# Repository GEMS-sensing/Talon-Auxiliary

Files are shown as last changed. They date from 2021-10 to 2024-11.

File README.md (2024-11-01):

<!-- [![DOI](https://zenodo.org/badge/678911830.svg)](https://zenodo.org/doi/10.5281/zenodo.13377368) -->

# Talon-Auxiliary
Talon daughterboard for [Flight data logger](https://github.com/GEMS-sensing/DFM_-_Flight?tab=readme-ov-file). Designed to interface with [Kestrel](https://github.com/GEMS-sensing/Project-Kestrel) main board. This board is designed to provide data logger with support to interface with analog and pulsed digital signals.
# Repo Roadmap
#### [Documents](Documents/) 

General document and image storage for repo and README

#### [Hardware](Hardware/)

Current board files (Eagle), Bill of Materials (BoM), and other design documents

#### [Production](Production/)

Contains the various Gerber and pick and place files required to have the Printed Circuit Boards (PCBs) manufactured or populated 

#### [Software](Software/)

The software associated with the piece of hardware, this is usually diagnostic software used for verifying or investigating the hardware

<!-- #### [Mechanical](Mechanical/)

Mechanical design files and assembly documents -->

<!-- #### [Testing](Testing/)

Scripts and results from the testing process and development process. Contains more detailed information about documented issues among other testing. 
 -->

## Overview
* **Type:** Talon
* **Interfaces:** Analog, digital, digital (open drain)
* **Release Version:** v1.5 - 2023/05/15

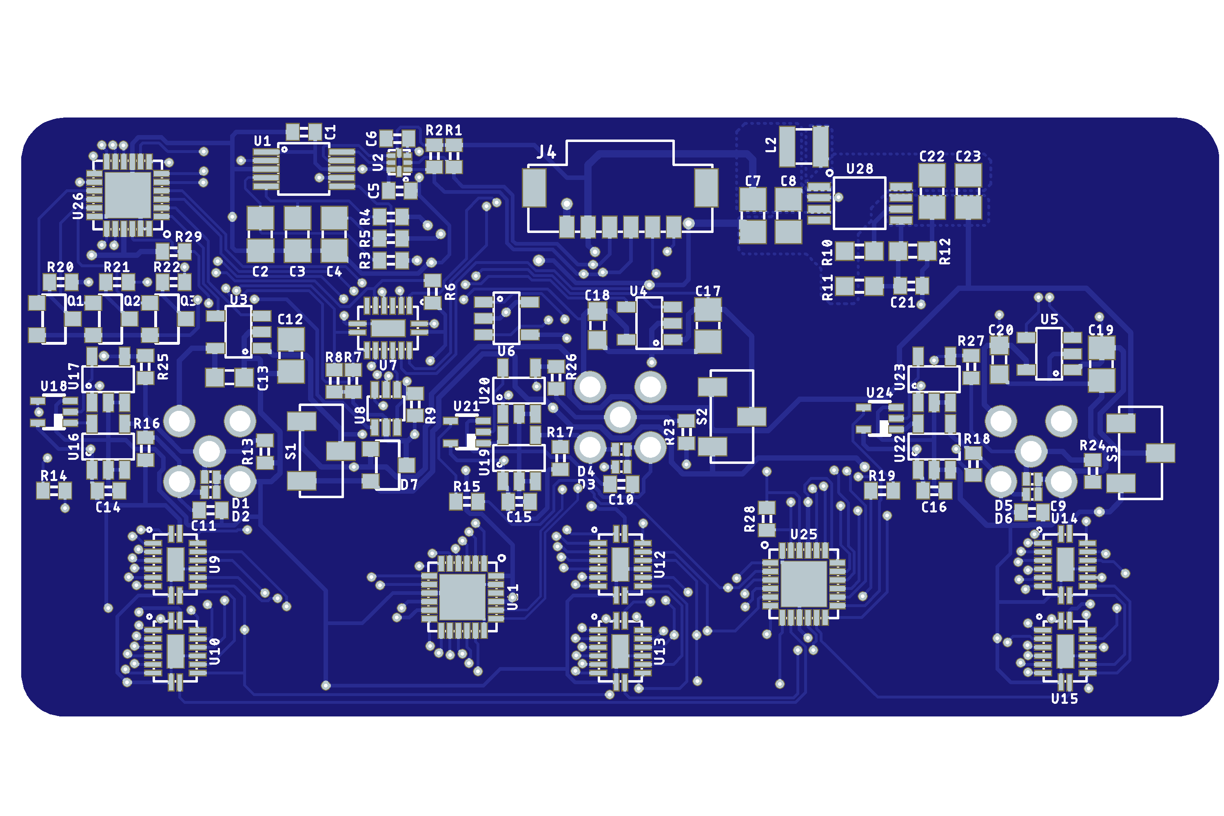
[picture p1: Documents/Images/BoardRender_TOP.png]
PCB render image, top


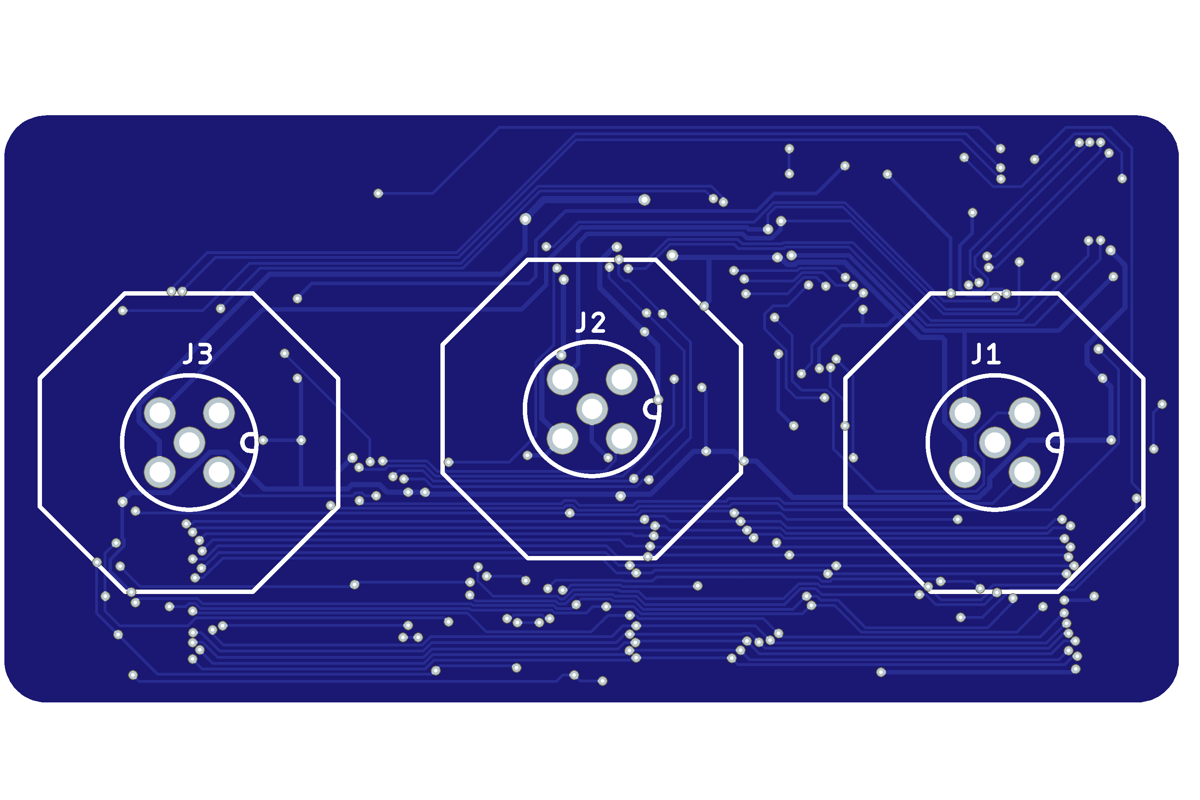
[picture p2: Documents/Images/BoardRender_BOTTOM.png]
PCB render image, bottom


<!-- ![Haar v0.0 - Bottom](Documents/Images/Haar_0v0_Bottom_Cropped.jpg) -->

## Features
### On-Board
* High precision ADC interface
	* 5V input
	* PGA
	* 16 bit (93.75 &mu;V @ 5V input, 3.9 &mu;V @ 0.25V input)
	* up to 860 SPS (reduced resolution)
* Hardware pulse counter
	* Reduces power consumption of logger by eliminating need to wake up SoM for frequent pulse interrupts 
	* 16 bit (65536) pulse count limit
	* Analog front end with hysteresis to deal with noisy inputs
	* Support for self diagnostics to allow for automated testing of operation 
* Push-pull and Open-drain compatible inputs 
* Load switch control for each port with current limiting 
* Manual switches to select each port between 3v3 and 5v power/logic
	* Chosen to be manual to prevent a firmware bug from damaging a sensor
* EEPROM with UUID built in - can store additional values defined by firmware to track offsets, etc
* ESD protected inputs

### Interface - Sensor
* I<sup>2</sup>C data interface
* M12 circular connector 

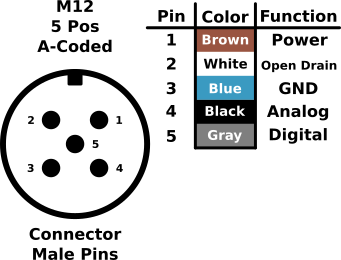
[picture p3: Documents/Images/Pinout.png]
Pinout


<!-- <picture>
  <source media="(prefers-color-scheme: dark)" srcset="Documents/Images/Pinout_LIGHT.png">
  <img alt="Hedorah Connector Pinout" src="Documents/Images/Pinout.png">
</picture> -->

| **Pin** | **Connection** | **Description** |
|---|---| --- |
| 1 | Power (3.3V  **OR** 5V) | Output power to sensors, limited to 50mA continuous current, voltage level is selected by DIP switch next to each port |
| 2 | Open Drain | Input for switch based sensors - 10k&Omega; pullup to Power rail|
| 3 | Ground | Power and data ground for system |
| 4 | Analog | Analog voltage input |
| 5 | Digital | Digital pulse input |

#### Sensor Wiring

- Switch based sensors
	- e.g. reed switch, hall effect, etc
	- Devices where the sensor open or closes a switch depending on state
	- Wire switch between Ground and Open Drain lines
	- WARNING: The Talon will apply rail power to the switch line via a pullup resistor - ensure the sensor is rated for the rail voltage being used (3.3V or 5V)
	- NOTE: To limit power consumption, only recommended for Nominally Open (NO) switches
- Pulse based sensors
	- e.g. microcontroller pulse outputs, basic digital sensors, etc
	- Devices where the output is either 0V or a logic voltage based based on a sensor state
	- Wire grounds together and wire the pulse output to the Digital pin, wire Power to sensor if needed
	- NOTE: The digital input is 5V tolerant regardless of the voltage on the power bus
- Analog based sensors
	- e.g. Potentiometers, basic sensors with variable voltage output, etc
	- Devices where the output is a voltage which varies with sensed value
	- Wire grounds together and wire the analog output of the sensor to the Analog pin, wire Power to sensor if needed
	- NOTE: The analog input is rated up to 5V regardless of the voltage on the power bus

#### Bus Selection
The power provided by each Aux Talon port can be selected as either 3.3V (default) or 5V - depending on the demands of the sensor.

This setting is changed by flipping the DIP switches (`S1`, `S2`, `S3`) on the Aux Talon itself, the position for a given voltage is noted next to each switch. Each switch controls the Aux Talon port it is adjacent to and each port can be switched independently of the others.

> [!WARNING]
> Application of voltage beyond the sensor specifications may result in irreparable damage to the sensor!

<!-- ### Interface
* I<sup>2</sup>C
* M12 circular connector  -->

<!-- <picture>
  <source media="(prefers-color-scheme: dark)" srcset="Documents/Pinout_LIGHT.png">
  <img alt="Haar Connector Pinout" src="Documents/Pinout.png">
</picture> -->

<!-- ## Specifications
* **Voltage - Supply:** 3.3V
* **Voltage - Logic:** 3.3V
* **Input Current (Avg, 1s period): 30.95&mu;A @ 3.3V**
* **Input Current (Avg, 5s period): 107.43&mu;A @ 3.3V**
* **Input Current (Max): 0.45mA @ 3.3V**

#### Sensor
**Temperature** [^1]
* Range: -40 ~ 125°C 
* Accuracy: &plusmn; 0.2°C
* Repeatability: &plusmn; 0.04°C

**Pressure** [^2]
* Range: 300 ~ 1200 hPa  
* Accuracy: &plusmn; 1 hPa
* Repeatability: &plusmn; 0.06 hPa

**Humidity** [^1]
* Range: 0 ~ 100%
* Accuracy: &plusmn; 2%
* Repeatability: 0.08%

[^1]: [SHT31 Datasheet](https://sensirion.com/media/documents/213E6A3B/63A5A569/Datasheet_SHT3x_DIS.pdf)
[^2]: [DPS368 Datasheet](https://www.infineon.com/dgdl/Infineon-DPS368-DS-v01_00-EN.pdf?fileId=5546d46269e1c019016a0c45105d4b40) -->

<!-- ## Version History

`v0.0` - Initial primal version with screw terminal

`v0.1` - Initial 'hard mount' version, using M12 connector

`v1.0` - Removed pullup select[^3], added logic level buffer and voltage reg on input

`v1.1` - Moved via away from connector pads to prevent bridging when soldering 

`v2.0` - Fixed issue with address select jumper[^3] -->

<!-- ## Jumper Settings 

> [!IMPORTANT]
> Jumper settings valid for version `v2.0` and beyond[^3]

[^3]: See Errata

**Configuration Jumpers**
| Jumper | Purpose | Open | Closed | Default | 
| --- | --- | --- | --- | ----- |
| `JP1` | I<sup>2</sup>C Address Select | Base Address<sup>&dagger;</sup> | Alt Address<sup>&Dagger;</sup> | Open |

&dagger; SHT31 = `0x44`, DPS368 = `0x76`

&Dagger; SHT31 = `0x44`, DPS368 = `0x77`
 -->

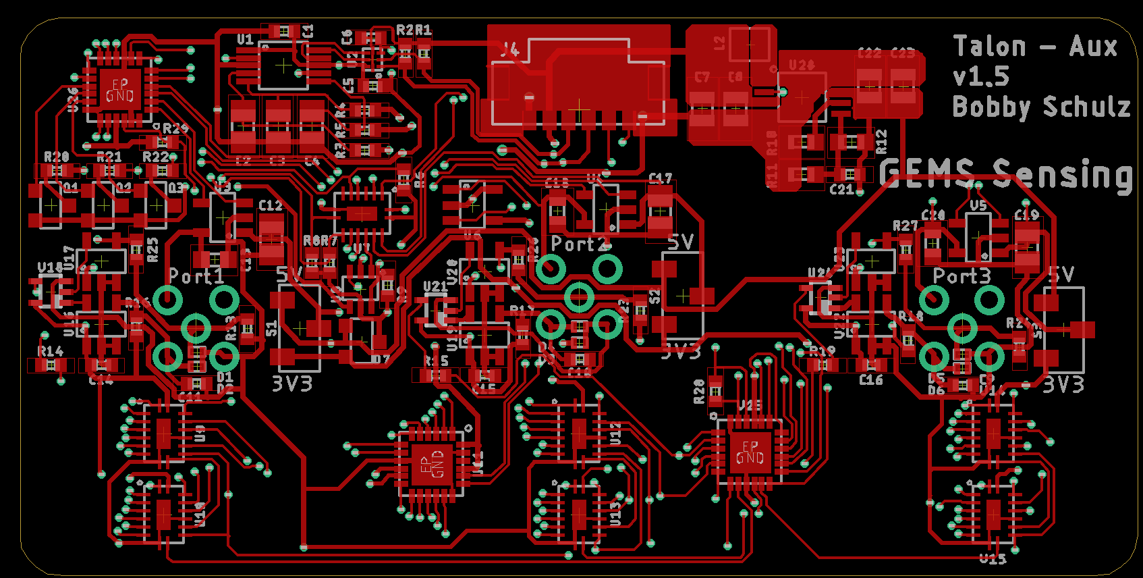
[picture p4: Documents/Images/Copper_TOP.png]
PCB trace CAD image, top


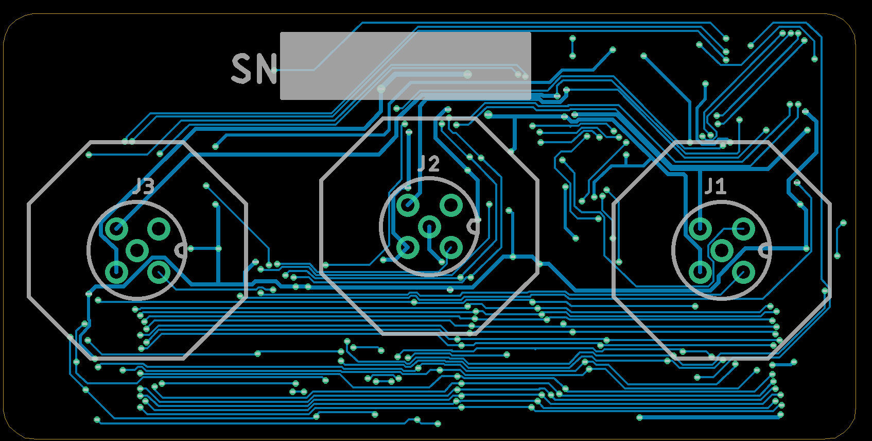
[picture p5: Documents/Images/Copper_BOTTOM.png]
PCB trace CAD, bottom


## Known Issues/Errata

None
<!-- #### Solder Jumper Stencil

**Version Affected:** All

**Issue:** Solar input does not support very low impedance sources (e.g. lead acid battery) - see details in issue [#20](https://github.com/GEMS-sensing/Project-Kestrel/issues/20)

**Workaround:** 

* Avoid use of low impedance batteries for input
* Include series impedance to prevent current spikes (not desirable)
* Perform board patch described in issue [#20](https://github.com/GEMS-sensing/Project-Kestrel/issues/20) -->

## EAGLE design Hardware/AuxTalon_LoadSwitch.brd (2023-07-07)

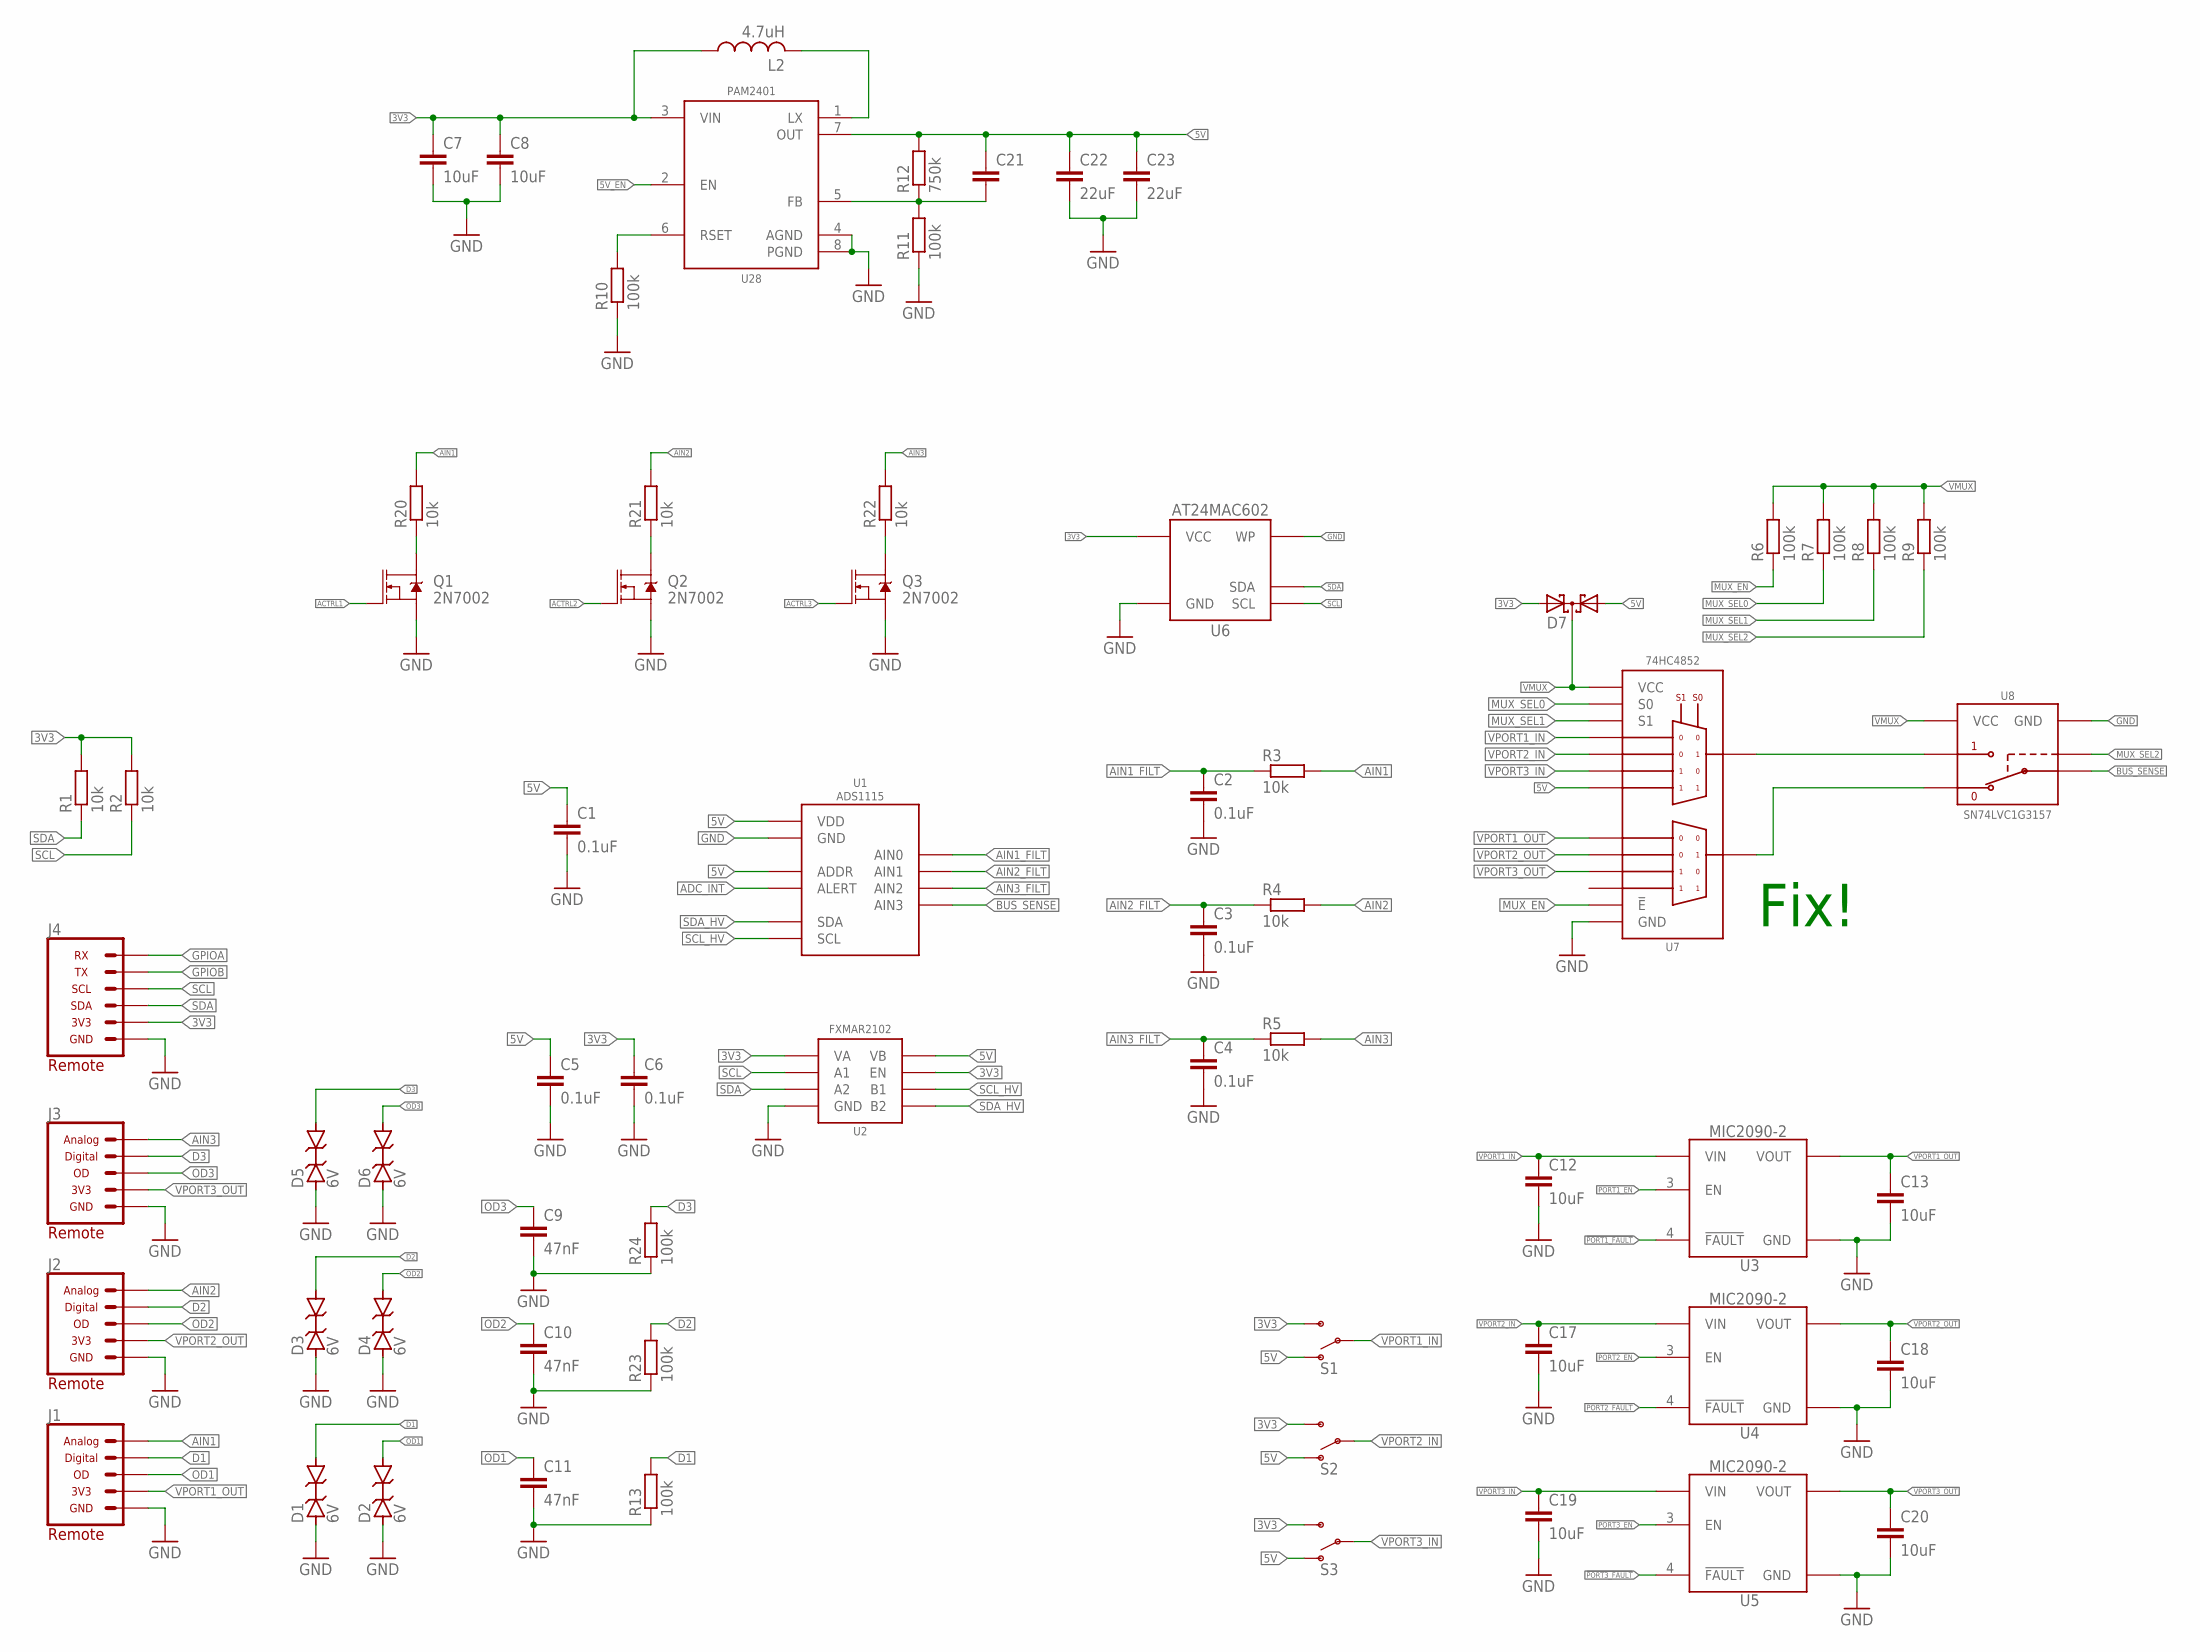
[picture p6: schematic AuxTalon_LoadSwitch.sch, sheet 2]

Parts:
C1, C5, C6: 0.1uF; C0402
C2, C3, C4: 0.1uF; C0805
C7, C8, C12, C17, C19: 10uF; C0805
C9, C10, C11: 47nF; C0402
C13, C18, C20: 10uF; C0603
C21: C-EUC0402; C0402; MPN DNP; DIGIKEY DNP
C22, C23: 22uF; C0805
D1, D2, D3, D4, D5, D6: 6V; D0402
D7: DIODE_CCBAT54CSOT23; SOT23-3
J1, J2, J3: CONN_AUX_M12_REMOTE; 1X05_M12_TE_T41410
J4: CONN_TALON_REMOTE; 1X06_MICROLOCKPLUS
L2: 4.7uH; WE-MAPI(2.5X2); MPN 74438323047; DIGIKEY 732-4848-1-ND
Q1, Q2, Q3: 2N7002; SOT23-3
R1, R2, R3, R4, R5, R20, R21, R22: 10k; R0402
R6, R7, R8, R9, R13, R23, R24: 100k; R0402
R10, R11: 100k; R0603
R12: 750k; R0603
S1, S2, S3: SPDTCAS-120A1; CAS-120A1
U1: ADS1115; VSSOP_10
U2: FXMAR2102UMLP; UQFN-8_1.4X1.2
U3, U4, U5: MIC2090-2; SOT23-5
U6: AT24MAC602SOT23; SOT23-5
U7: 74HC4852; VQFN-16
U8: SN74LVC1G3157SC70; DCK_R-PDSO-G6
U28: PAM2401MSOP; MSOP_8

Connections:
3V3: C6.1, C7.1, C8.1, D7.2 (A2), J4.2 (3V3), L2.P$1 (1), R1.2, R2.2, S1.3 (S), S2.3 (S), S3.3 (S), U2.1 (VA), U2.5 (EN), U6.4 (VCC), U28.3 (VIN); also elsewhere on the board
5V: C1.1, C5.1, C21.1, C22.1, C23.1, D7.1 (A1), R12.2, S1.1 (O), S2.1 (O), S3.1 (O), U1.1 (ADDR), U1.8 (VDD), U2.8 (VB), U7.11 (1Y3), U28.7 (OUT)
5V_EN: U28.2 (EN); also elsewhere on the board
!PORT1_FAULT: U3.4 (!FAULT); also elsewhere on the board
!PORT2_FAULT: U4.4 (!FAULT); also elsewhere on the board
!PORT3_FAULT: U5.4 (!FAULT); also elsewhere on the board
ACTRL1: Q1.1 (G); also elsewhere on the board
ACTRL2: Q2.1 (G); also elsewhere on the board
ACTRL3: Q3.1 (G); also elsewhere on the board
ADC_INT: U1.2 (ALERT); also elsewhere on the board
AIN1: J1.4 (ANALOG), R3.2, R20.2
AIN1_FILT: C2.1, R3.1, U1.4 (AIN0)
AIN2: J2.4 (ANALOG), R4.2, R21.2
AIN2_FILT: C3.1, R4.1, U1.5 (AIN1)
AIN3: J3.4 (ANALOG), R5.2, R22.2
AIN3_FILT: C4.1, R5.1, U1.6 (AIN2)
BUS_SENSE: U1.7 (AIN3), U8.4 (A)
D1: D1.2 (C), J1.5 (DIGITAL), R13.2; also elsewhere on the board
D2: D3.2 (C), J2.5 (DIGITAL), R23.2; also elsewhere on the board
D3: D5.2 (C), J3.5 (DIGITAL), R24.2; also elsewhere on the board
GND: C1.2, C2.2, C3.2, C4.2, C5.2, C6.2, C7.2, C8.2, C9.2, C10.2, C11.2, C12.2, C13.2, C17.2, C18.2, C19.2, C20.2, C22.2, C23.2, D1.1 (A), D2.1 (A), D3.1 (A), D4.1 (A), D5.1 (A), D6.1 (A), J1.3 (GND), J2.3 (GND), J3.3 (GND), J4.1 (GND), Q1.2 (S), Q2.2 (S), Q3.2 (S), R10.1, R11.1, R13.1, R23.1, R24.1, U1.3 (GND), U2.4 (GND), U3.2 (GND), U4.2 (GND), U5.2 (GND), U6.2 (GND), U6.5 (WP), U7.8 (GND), U7.EP (GND), U8.2 (GND), U28.4 (AGND), U28.8 (PGND); also elsewhere on the board
GPIOA: J4.6 (RX); also elsewhere on the board
GPIOB: J4.5 (TX); also elsewhere on the board
MUX_EN: R6.1, U7.6 (!E); also elsewhere on the board
MUX_SEL0: R7.1, U7.10 (S0); also elsewhere on the board
MUX_SEL1: R8.1, U7.9 (S1); also elsewhere on the board
MUX_SEL2: R9.1, U8.6 (S); also elsewhere on the board
unnamed: U7.3 (2Z), U8.3 (B1)
unnamed: R10.2, U28.6 (RSET)
unnamed: C21.2, R11.2, R12.1, U28.5 (FB)
unnamed: Q3.3 (D), R22.1
unnamed: Q2.3 (D), R21.1
unnamed: Q1.3 (D), R20.1
unnamed: L2.P$2 (2), U28.1 (LX)
unnamed: U7.13 (1Z), U8.1 (B2)
OD1: C11.1, D2.2 (C), J1.2 (DIGITAL_OPENDRAIN); also elsewhere on the board
OD2: C10.1, D4.2 (C), J2.2 (DIGITAL_OPENDRAIN); also elsewhere on the board
OD3: C9.1, D6.2 (C), J3.2 (DIGITAL_OPENDRAIN); also elsewhere on the board
PORT1_EN: U3.3 (EN); also elsewhere on the board
PORT2_EN: U4.3 (EN); also elsewhere on the board
PORT3_EN: U5.3 (EN); also elsewhere on the board
SCL: J4.4 (SCL), R2.1, U2.2 (A1), U6.1 (SCL); also elsewhere on the board
SCL_HV: U1.10 (SCL), U2.7 (B1)
SDA: J4.3 (SDA), R1.1, U2.3 (A2), U6.3 (SDA); also elsewhere on the board
SDA_HV: U1.9 (SDA), U2.6 (B2)
VMUX: D7.3 (C), R6.2, R7.2, R8.2, R9.2, U7.16 (VCC), U8.5 (VCC)
VPORT1_IN: C12.1, S1.2, U3.1 (VIN), U7.12 (1Y0)
VPORT1_OUT: C13.1, J1.1 (3V3), U3.5 (VOUT), U7.1 (2Y0)
VPORT2_IN: C17.1, S2.2, U4.1 (VIN), U7.14 (1Y1)
VPORT2_OUT: C18.1, J2.1 (3V3), U4.5 (VOUT), U7.5 (2Y1)
VPORT3_IN: C19.1, S3.2, U5.1 (VIN), U7.15 (1Y2)
VPORT3_OUT: C20.1, J3.1 (3V3), U5.5 (VOUT), U7.2 (2Y2)

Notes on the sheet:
Fix!

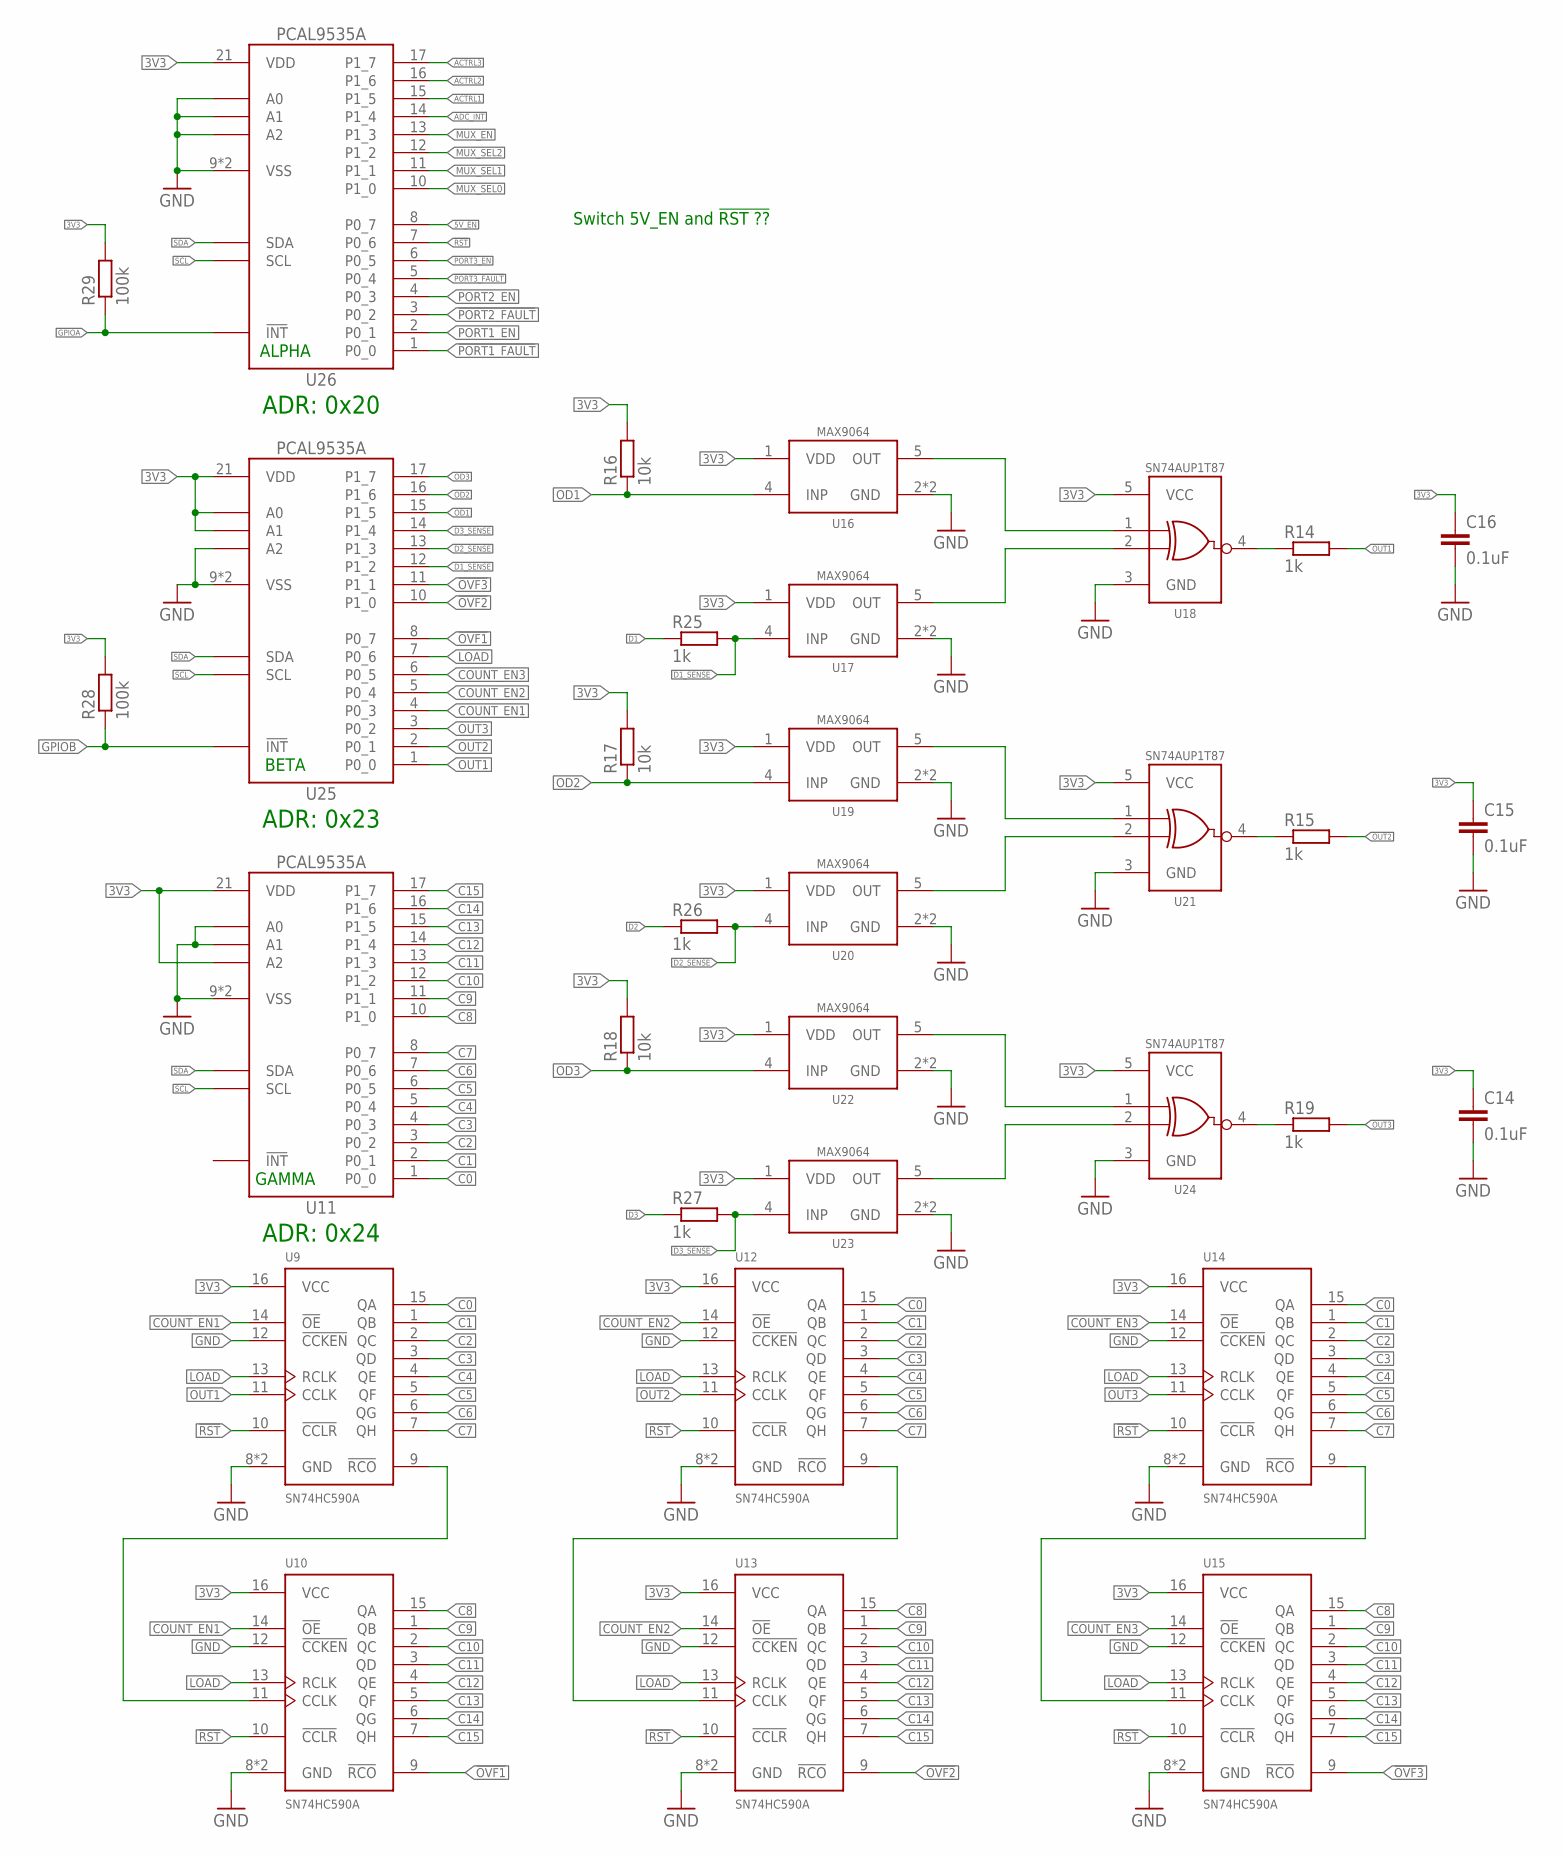
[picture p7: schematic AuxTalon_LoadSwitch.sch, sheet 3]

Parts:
C14, C15, C16: 0.1uF; C0402
R14, R15, R19, R25, R26, R27: 1k; R0402
R16, R17, R18: 10k; R0402
R28, R29: 100k; R0402
U9, U10, U12, U13, U14, U15: SN74HC590AVQFN; VQFN-16
U11, U25, U26: PCAL9535AQFN; QFN24
U16, U17, U19, U20, U22, U23: MAX9064; SOT23-5
U18, U21, U24: SN74AUP1T87; DCK_R-PDSO-G5

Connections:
3V3: C14.1, C15.1, C16.1, R16.2, R17.2, R18.2, R28.2, R29.2, U9.16 (VCC), U10.16 (VCC), U11.21 (VDD), U11.24 (A2), U12.16 (VCC), U13.16 (VCC), U14.16 (VCC), U15.16 (VCC), U16.1 (VDD), U17.1 (VDD), U18.5 (VCC), U19.1 (VDD), U20.1 (VDD), U21.5 (VCC), U22.1 (VDD), U23.1 (VDD), U24.5 (VCC), U25.18 (A0), U25.21 (VDD), U25.23 (A1), U26.21 (VDD); also elsewhere on the board
5V_EN: U26.8 (P0_7); also elsewhere on the board
!OVF1: U10.9 (!RCO), U25.8 (P0_7)
!OVF2: U13.9 (!RCO), U25.10 (P1_0)
!OVF3: U15.9 (!RCO), U25.11 (P1_1)
!PORT1_FAULT: U26.1 (P0_0); also elsewhere on the board
!PORT2_FAULT: U26.3 (P0_2); also elsewhere on the board
!PORT3_FAULT: U26.5 (P0_4); also elsewhere on the board
!RST: U9.10 (!CCLR), U10.10 (!CCLR), U12.10 (!CCLR), U13.10 (!CCLR), U14.10 (!CCLR), U15.10 (!CCLR), U26.7 (P0_6)
ACTRL1: U26.15 (P1_5); also elsewhere on the board
ACTRL2: U26.16 (P1_6); also elsewhere on the board
ACTRL3: U26.17 (P1_7); also elsewhere on the board
ADC_INT: U26.14 (P1_4); also elsewhere on the board
C0: U9.15 (QA), U11.1 (P0_0), U12.15 (QA), U14.15 (QA)
C1: U9.1 (QB), U11.2 (P0_1), U12.1 (QB), U14.1 (QB)
C2: U9.2 (QC), U11.3 (P0_2), U12.2 (QC), U14.2 (QC)
C3: U9.3 (QD), U11.4 (P0_3), U12.3 (QD), U14.3 (QD)
C4: U9.4 (QE), U11.5 (P0_4), U12.4 (QE), U14.4 (QE)
C5: U9.5 (QF), U11.6 (P0_5), U12.5 (QF), U14.5 (QF)
C6: U9.6 (QG), U11.7 (P0_6), U12.6 (QG), U14.6 (QG)
C7: U9.7 (QH), U11.8 (P0_7), U12.7 (QH), U14.7 (QH)
C8: U10.15 (QA), U11.10 (P1_0), U13.15 (QA), U15.15 (QA)
C9: U10.1 (QB), U11.11 (P1_1), U13.1 (QB), U15.1 (QB)
C10: U10.2 (QC), U11.12 (P1_2), U13.2 (QC), U15.2 (QC)
C11: U10.3 (QD), U11.13 (P1_3), U13.3 (QD), U15.3 (QD)
C12: U10.4 (QE), U11.14 (P1_4), U13.4 (QE), U15.4 (QE)
C13: U10.5 (QF), U11.15 (P1_5), U13.5 (QF), U15.5 (QF)
C14: U10.6 (QG), U11.16 (P1_6), U13.6 (QG), U15.6 (QG)
C15: U10.7 (QH), U11.17 (P1_7), U13.7 (QH), U15.7 (QH)
COUNT_EN1: U9.14 (!OE), U10.14 (!OE), U25.4 (P0_3)
COUNT_EN2: U12.14 (!OE), U13.14 (!OE), U25.5 (P0_4)
COUNT_EN3: U14.14 (!OE), U15.14 (!OE), U25.6 (P0_5)
D1: R25.1; also elsewhere on the board
D1_SENSE: R25.2, U17.4 (INP), U25.12 (P1_2)
D2: R26.1; also elsewhere on the board
D2_SENSE: R26.2, U20.4 (INP), U25.13 (P1_3)
D3: R27.1; also elsewhere on the board
D3_SENSE: R27.2, U23.4 (INP), U25.14 (P1_4)
GND: C14.2, C15.2, C16.2, U9.8 (GND), U9.12 (!CCKEN), U9.EP (GND), U10.8 (GND), U10.12 (!CCKEN), U10.EP (GND), U11.9 (VSS), U11.18 (A0), U11.23 (A1), U11.EP (VSS), U12.8 (GND), U12.12 (!CCKEN), U12.EP (GND), U13.8 (GND), U13.12 (!CCKEN), U13.EP (GND), U14.8 (GND), U14.12 (!CCKEN), U14.EP (GND), U15.8 (GND), U15.12 (!CCKEN), U15.EP (GND), U16.2 (GND), U16.3 (GND), U17.2 (GND), U17.3 (GND), U18.3 (GND), U19.2 (GND), U19.3 (GND), U20.2 (GND), U20.3 (GND), U21.3 (GND), U22.2 (GND), U22.3 (GND), U23.2 (GND), U23.3 (GND), U24.3 (GND), U25.9 (VSS), U25.24 (A2), U25.EP (VSS), U26.9 (VSS), U26.18 (A0), U26.23 (A1), U26.24 (A2), U26.EP (VSS); also elsewhere on the board
GPIOA: R29.1, U26.22 (!INT); also elsewhere on the board
GPIOB: R28.1, U25.22 (!INT); also elsewhere on the board
LOAD: U9.13 (RCLK), U10.13 (RCLK), U12.13 (RCLK), U13.13 (RCLK), U14.13 (RCLK), U15.13 (RCLK), U25.7 (P0_6)
MUX_EN: U26.13 (P1_3); also elsewhere on the board
MUX_SEL0: U26.10 (P1_0); also elsewhere on the board
MUX_SEL1: U26.11 (P1_1); also elsewhere on the board
MUX_SEL2: U26.12 (P1_2); also elsewhere on the board
unnamed: U9.9 (!RCO), U10.11 (CCLK)
unnamed: U12.9 (!RCO), U13.11 (CCLK)
unnamed: U14.9 (!RCO), U15.11 (CCLK)
unnamed: U20.5 (OUT), U21.2 (B)
unnamed: U19.5 (OUT), U21.1 (A)
unnamed: U16.5 (OUT), U18.1 (A)
unnamed: U17.5 (OUT), U18.2 (B)
unnamed: U23.5 (OUT), U24.2 (B)
unnamed: U22.5 (OUT), U24.1 (A)
unnamed: R14.1, U18.4 (Y)
unnamed: R15.1, U21.4 (Y)
unnamed: R19.1, U24.4 (Y)
OD1: R16.1, U16.4 (INP), U25.15 (P1_5); also elsewhere on the board
OD2: R17.1, U19.4 (INP), U25.16 (P1_6); also elsewhere on the board
OD3: R18.1, U22.4 (INP), U25.17 (P1_7); also elsewhere on the board
OUT1: R14.2, U9.11 (CCLK), U25.1 (P0_0)
OUT2: R15.2, U12.11 (CCLK), U25.2 (P0_1)
OUT3: R19.2, U14.11 (CCLK), U25.3 (P0_2)
PORT1_EN: U26.2 (P0_1); also elsewhere on the board
PORT2_EN: U26.4 (P0_3); also elsewhere on the board
PORT3_EN: U26.6 (P0_5); also elsewhere on the board
SCL: U11.19 (SCL), U25.19 (SCL), U26.19 (SCL); also elsewhere on the board
SDA: U11.20 (SDA), U25.20 (SDA), U26.20 (SDA); also elsewhere on the board

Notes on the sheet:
BETA
GAMMA
ALPHA
ADR: 0x20
ADR: 0x23
ADR: 0x24
Switch 5V_EN and !RST ??

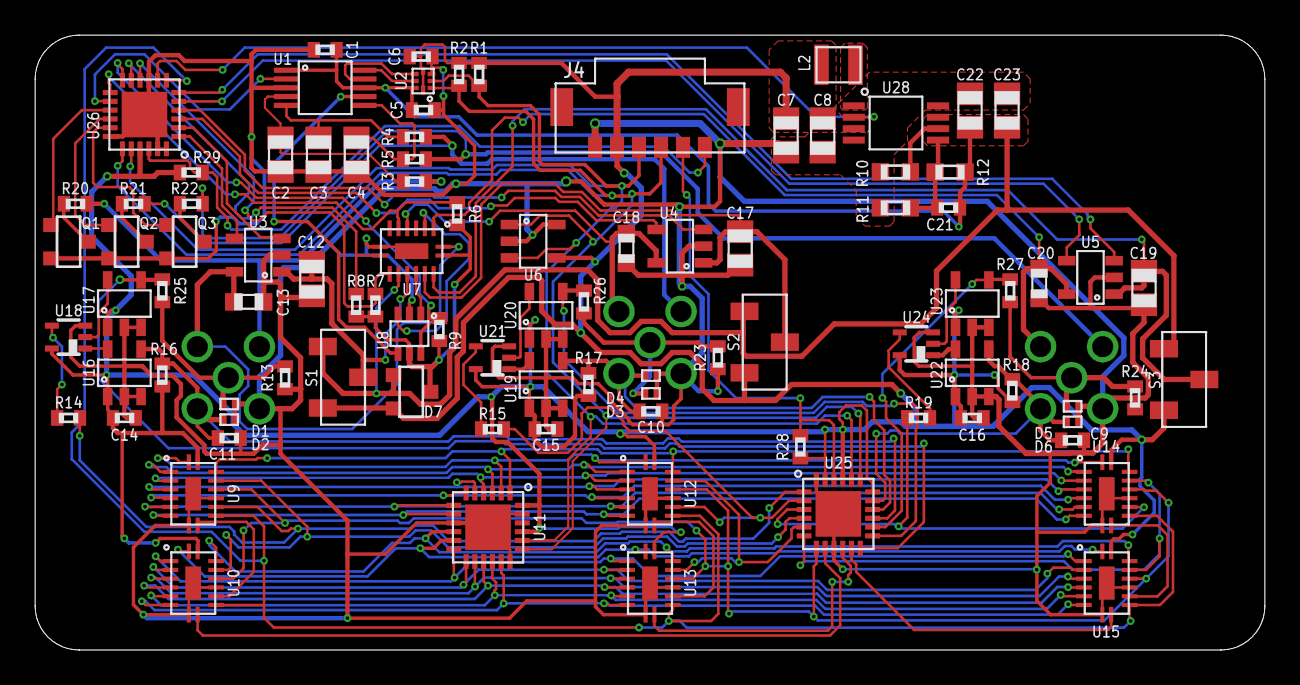
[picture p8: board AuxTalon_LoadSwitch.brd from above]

Board: 2 copper layers, 70.0 x 35.0 mm, 97 parts (0 on the bottom side), 94 nets.

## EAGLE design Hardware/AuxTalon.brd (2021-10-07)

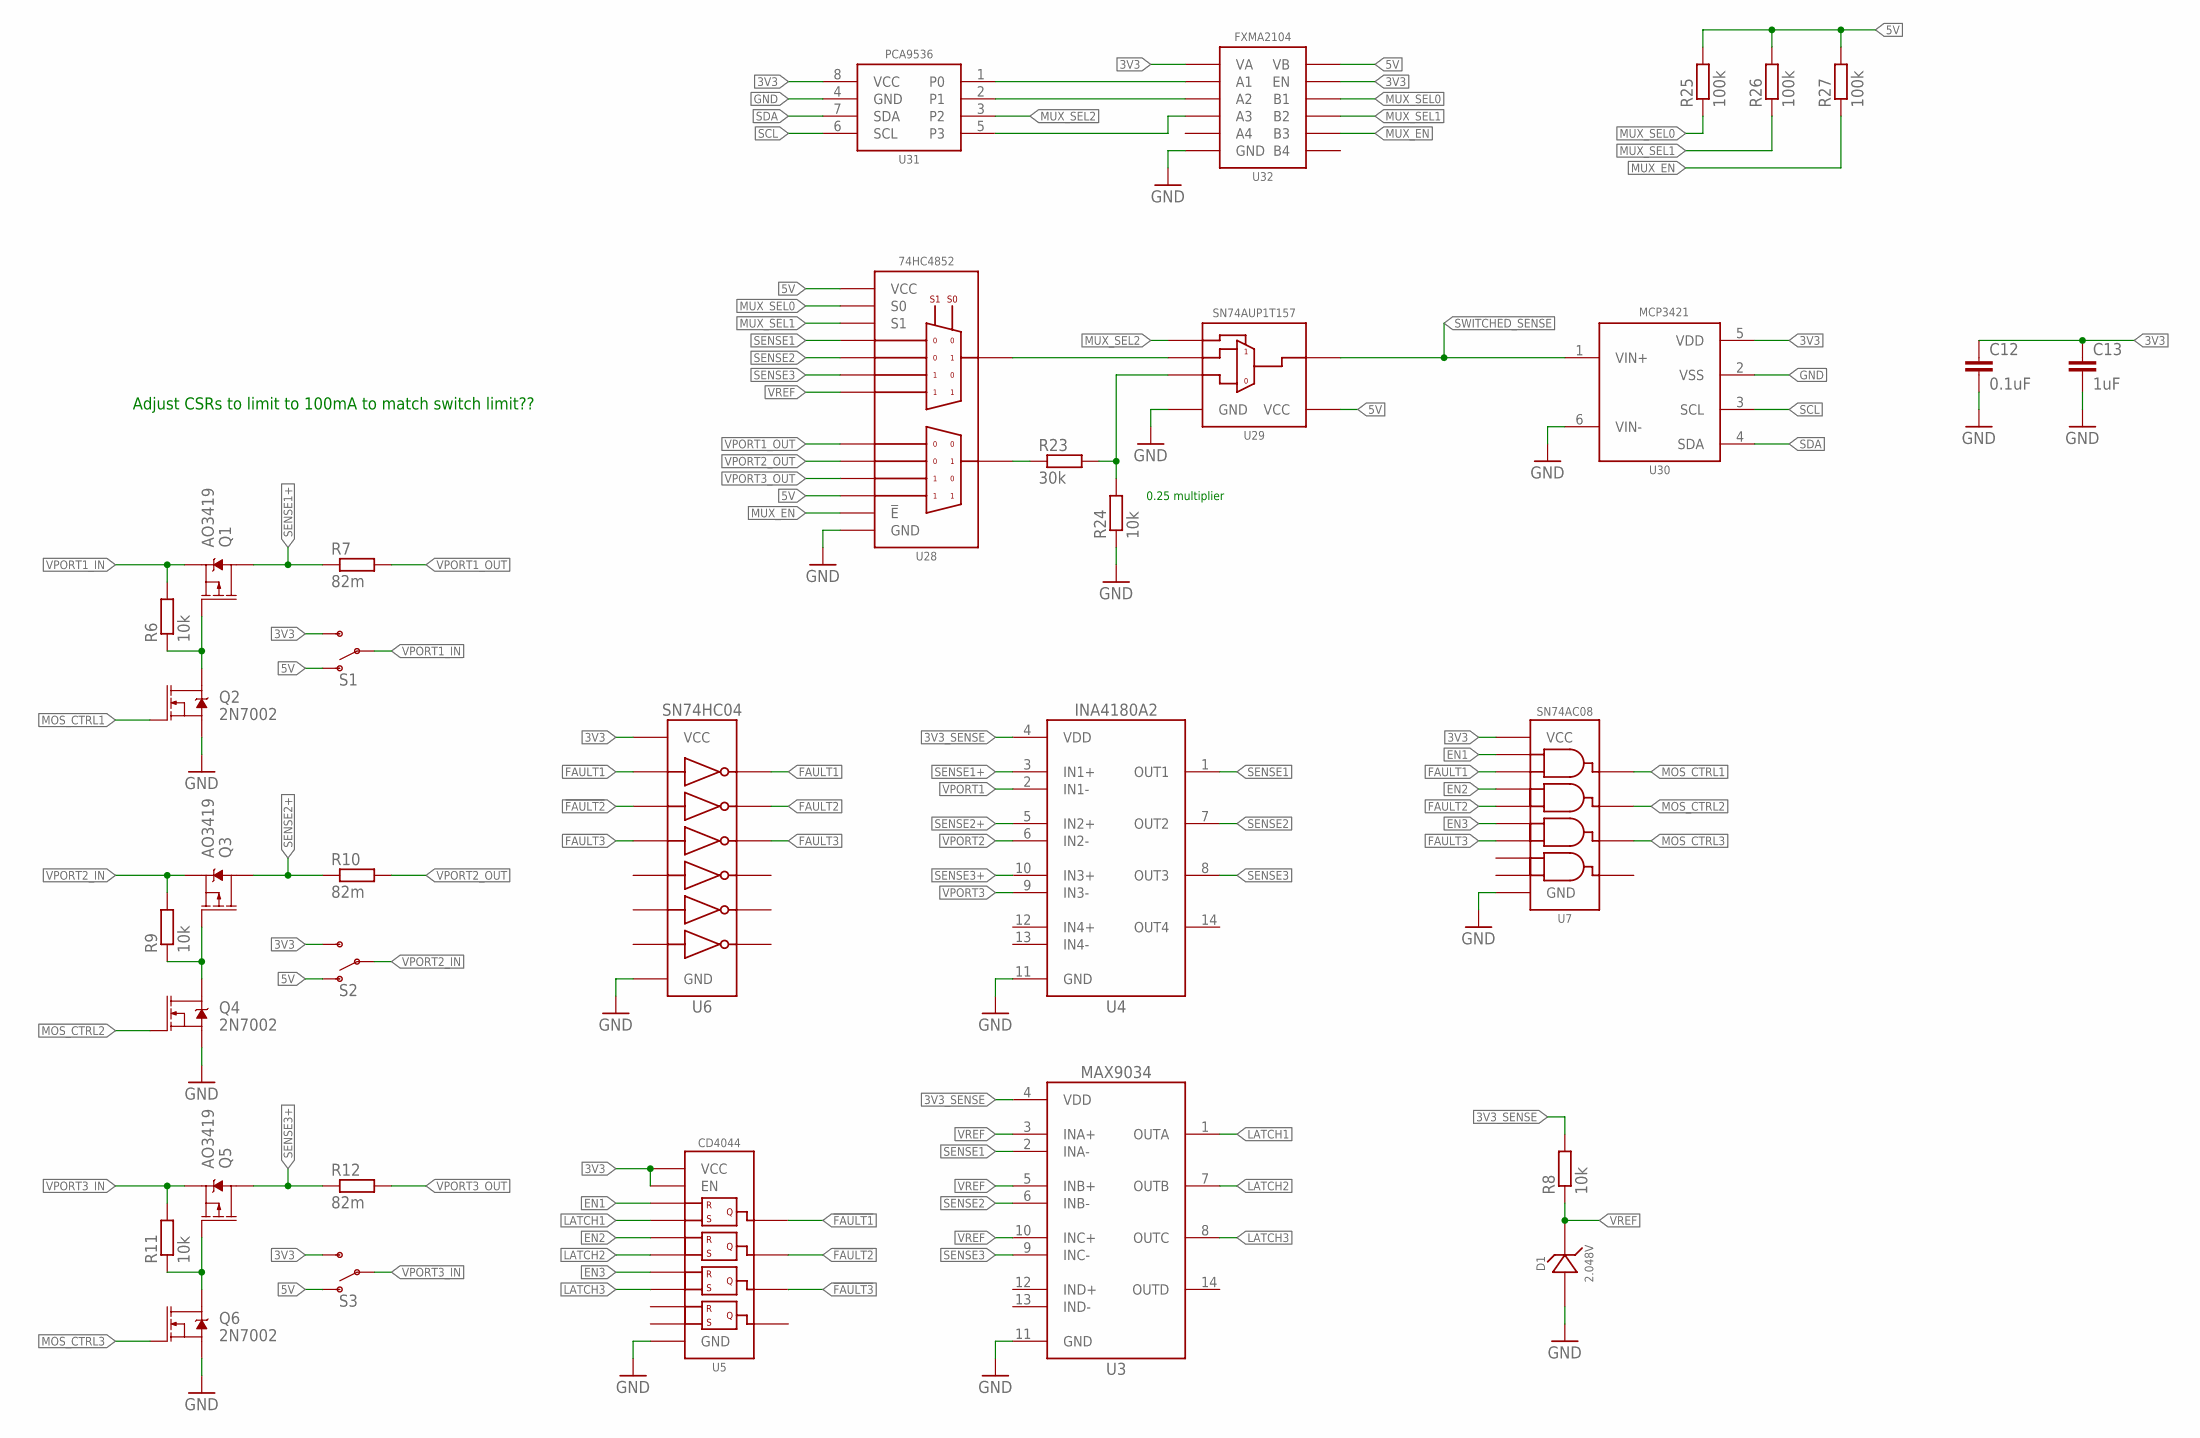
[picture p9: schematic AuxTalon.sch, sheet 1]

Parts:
C12: 0.1uF; C0402
C13: 1uF; C0805
D1: 2.048V; SOT23-3
Q1, Q3, Q5: AO3419; SOT23-3
Q2, Q4, Q6: 2N7002; SOT23-3
R6, R8, R9, R11, R24: 10k; R0402
R7, R10, R12: 82m; R0603
R23: 30k; R0402
R25, R26, R27: 100k; R0402
S1, S2, S3: SPDTCAS-120A1; CAS-120A1
U3: MAX9034TSSOP; TSSOP14
U4: INA4180A2; TSSOP14
U5: CD4044; TSSOP16
U6: SN74HC04; TSSOP14
U7: SN74AC08; TSSOP14
U28: 74HC4852; VQFN-16
U29: SN74AUP1T157DCK; DCK_R-PDSO-G6
U30: MCP3421A3; SOT23-6L
U31: PCA9536DFN; DFN_8_3X3
U32: FXMA2104; MLP_12

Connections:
3V3: C12.1, C13.1, S1.3 (S), S2.3 (S), S3.3 (S), U5.5 (EN), U5.16 (VCC), U6.14 (VCC), U7.14 (VCC), U30.5 (VDD), U31.8 (VCC), U32.2 (VA), U32.8 (EN); also elsewhere on the board
3V3_SENSE: R8.2, U3.4 (VDD), U4.4 (VDD); also elsewhere on the board
5V: R25.2, R26.2, R27.2, S1.1 (O), S2.1 (O), S3.1 (O), U28.4 (2Y3), U28.16 (VCC), U29.5 (VCC), U32.1 (VB); also elsewhere on the board
!FAULT1: U5.13 (Q1), U6.1 (A1); also elsewhere on the board
!FAULT2: U5.9 (Q2), U6.3 (A2); also elsewhere on the board
!FAULT3: U5.10 (Q3), U6.5 (A3); also elsewhere on the board
EN1: U5.4 (R1), U7.1 (A1); also elsewhere on the board
EN2: U5.6 (R2), U7.4 (A2); also elsewhere on the board
EN3: U5.12 (R3), U7.9 (A3); also elsewhere on the board
FAULT1: U6.2 (Y1), U7.2 (B1)
FAULT2: U6.4 (Y2), U7.5 (B2)
FAULT3: U6.6 (Y3), U7.10 (B3)
GND: C12.2, C13.2, D1.2 (A), Q2.2 (S), Q4.2 (S), Q6.2 (S), R24.1, U3.11 (GND), U4.11 (GND), U5.8 (GND), U6.7 (GND), U7.7 (GND), U28.8 (GND), U28.EP (GND), U29.2 (GND), U30.2 (VSS), U30.6 (VIN-), U31.4 (GND), U32.7 (GND); also elsewhere on the board
LATCH1: U3.1 (OUTA), U5.3 (S1)
LATCH2: U3.7 (OUTB), U5.7 (S2)
LATCH3: U3.8 (OUTC), U5.11 (S3)
MOS_CTRL1: Q2.1 (G), U7.3 (Y1)
MOS_CTRL2: Q4.1 (G), U7.6 (Y2)
MOS_CTRL3: Q6.1 (G), U7.8 (Y3)
MUX_EN: R27.1, U28.6 (!E), U32.10 (B3)
MUX_SEL0: R25.1, U28.10 (S0), U32.12 (B1)
MUX_SEL1: R26.1, U28.9 (S1), U32.11 (B2)
MUX_SEL2: U29.4 (C), U31.3 (P2); also elsewhere on the board
unnamed: Q3.1 (G), Q4.3 (D), R9.1
unnamed: Q1.1 (G), Q2.3 (D), R6.1
unnamed: Q5.1 (G), Q6.3 (D), R11.1
unnamed: R23.1, U28.3 (2Z)
unnamed: R23.2, R24.2, U29.3 (B)
unnamed: U31.1 (P0), U32.3 (A1)
unnamed: U31.2 (P1), U32.4 (A2)
unnamed: U31.5 (P3), U32.5 (A3)
unnamed: U28.13 (1Z), U29.1 (A)
SCL: U30.3 (SCL), U31.6 (SCL); also elsewhere on the board
SDA: U30.4 (SDA), U31.7 (SDA); also elsewhere on the board
SENSE1: U3.2 (INA-), U4.1 (OUT1), U28.12 (1Y0)
SENSE1+: Q1.3 (D), R7.1, U4.3 (IN1+)
SENSE2: U3.6 (INB-), U4.7 (OUT2), U28.14 (1Y1)
SENSE2+: Q3.3 (D), R10.1, U4.5 (IN2+)
SENSE3: U3.9 (INC-), U4.8 (OUT3), U28.15 (1Y2)
SENSE3+: Q5.3 (D), R12.1, U4.10 (IN3+)
SWITCHED_SENSE: U29.6 (Y), U30.1 (VIN+)
VPORT1: U4.2 (IN1-)
VPORT1_IN: Q1.2 (S), R6.2, S1.2
VPORT1_OUT: R7.2, U28.1 (2Y0); also elsewhere on the board
VPORT2: U4.6 (IN2-)
VPORT2_IN: Q3.2 (S), R9.2, S2.2
VPORT2_OUT: R10.2, U28.5 (2Y1); also elsewhere on the board
VPORT3: U4.9 (IN3-)
VPORT3_IN: Q5.2 (S), R11.2, S3.2
VPORT3_OUT: R12.2, U28.2 (2Y2); also elsewhere on the board
VREF: D1.1 (C), R8.1, U3.3 (INA+), U3.5 (INB+), U3.10 (INC+), U28.11 (1Y3); also elsewhere on the board

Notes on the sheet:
Adjust CSRs to limit to 100mA to match switch limit??
0.25 multiplier

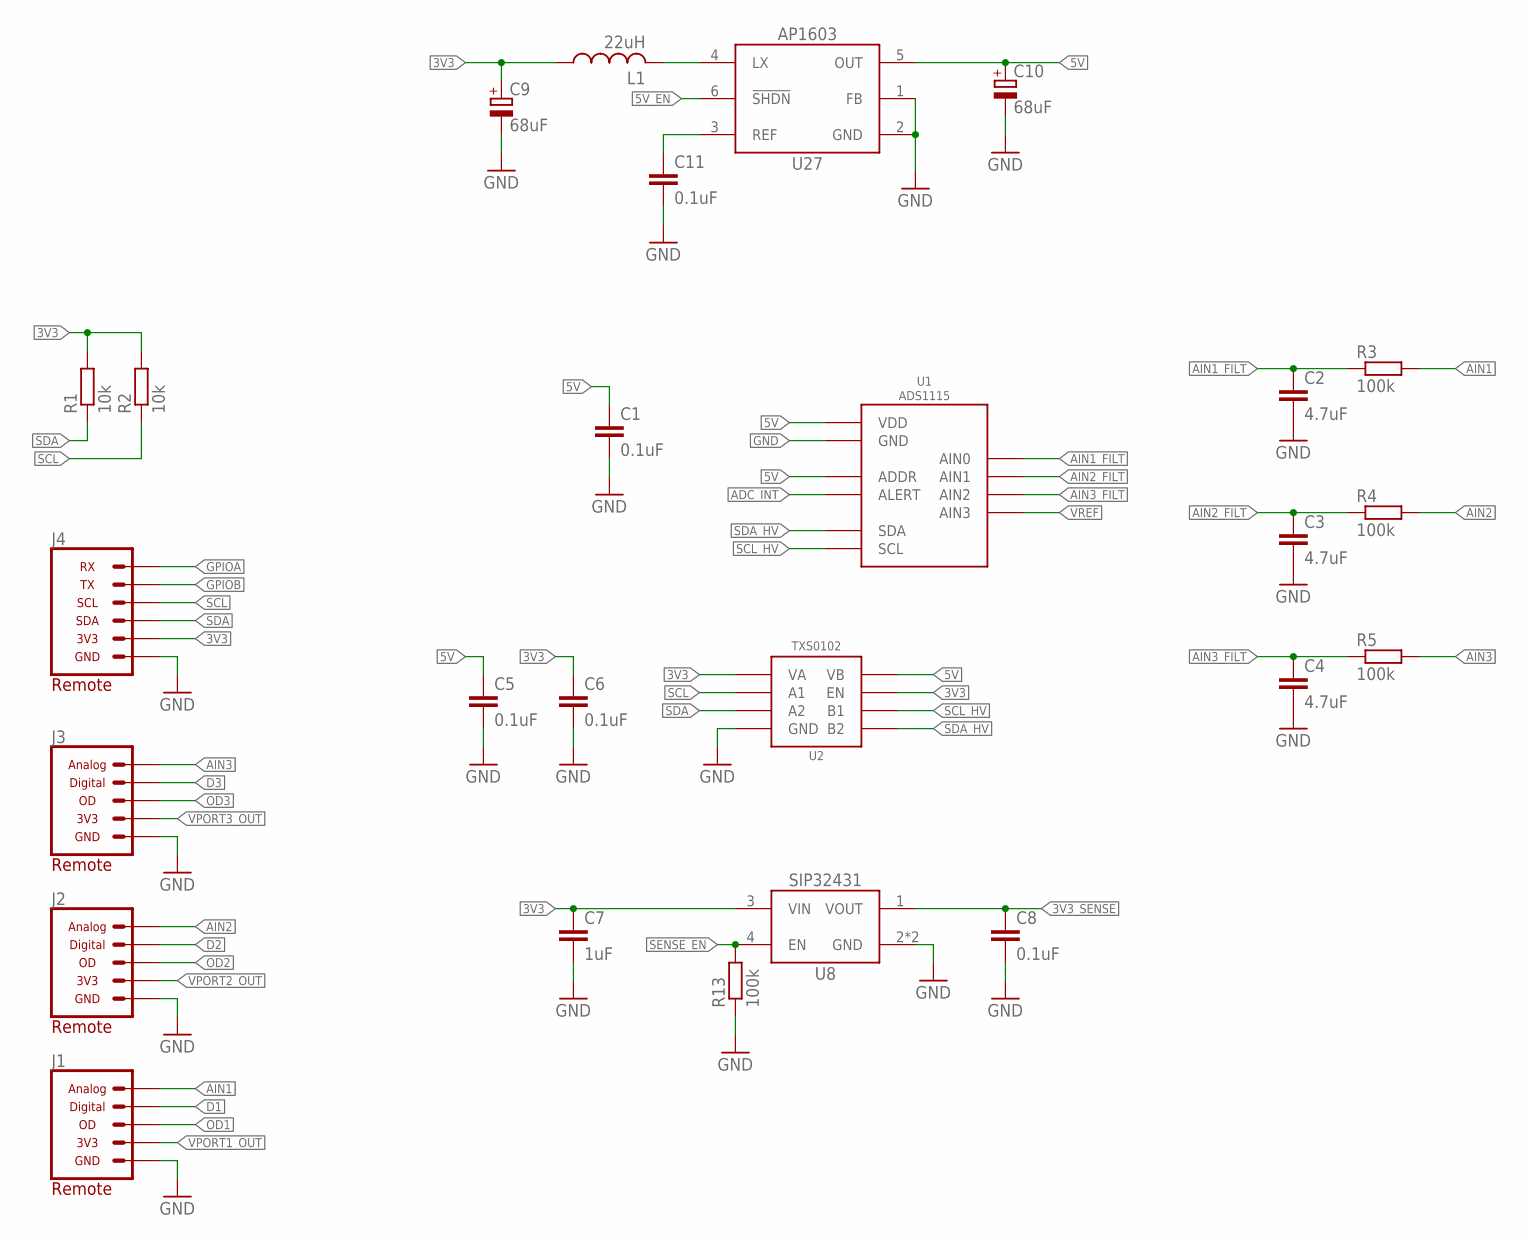
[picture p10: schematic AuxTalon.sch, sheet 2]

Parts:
C1, C5, C6, C8, C11: 0.1uF; C0402
C2, C3, C4: 4.7uF; C0805
C7: 1uF; C0603
C9, C10: 68uF; 153CLV-0605
J1, J2, J3: CONN_AUX_M12_REMOTE; 1X05_M12_TE_T41410
J4: CONN_TALON_REMOTE; 1X06_MICROLOCKPLUS
L1: 22uH; WE-TPC(3.8X3.8)
R1, R2: 10k; R0402
R3, R4, R5, R13: 100k; R0402
U1: ADS1115; VSSOP_10
U2: TXS0102DCU; DCU_(R-PDSO-G8)
U8: SIP32431TDFN; TDFN_4
U27: AP1603; TSOT23-6_DDC

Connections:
3V3: C6.1, C7.1, C9.+, J4.5 (3V3), L1.1, R1.2, R2.2, U2.3 (VA), U2.6 (EN), U8.3 (VIN); also elsewhere on the board
3V3_SENSE: C8.1, U8.1 (VOUT); also elsewhere on the board
5V: C1.1, C5.1, C10.+, U1.1 (ADDR), U1.8 (VDD), U2.7 (VB), U27.5 (OUT); also elsewhere on the board
5V_EN: U27.6 (!SHDN); also elsewhere on the board
ADC_INT: U1.2 (ALERT)
AIN1: J1.4 (ANALOG), R3.2
AIN1_FILT: C2.1, R3.1, U1.4 (AIN0)
AIN2: J2.4 (ANALOG), R4.2
AIN2_FILT: C3.1, R4.1, U1.5 (AIN1)
AIN3: J3.4 (ANALOG), R5.2
AIN3_FILT: C4.1, R5.1, U1.6 (AIN2)
D1: J1.5 (DIGITAL); also elsewhere on the board
D2: J2.5 (DIGITAL); also elsewhere on the board
D3: J3.5 (DIGITAL); also elsewhere on the board
GND: C1.2, C2.2, C3.2, C4.2, C5.2, C6.2, C7.2, C8.2, C9.-, C10.-, C11.2, J1.3 (GND), J2.3 (GND), J3.3 (GND), J4.6 (GND), R13.1, U1.3 (GND), U2.2 (GND), U8.2 (GND), U8.EP (GND), U27.1 (FB), U27.2 (GND); also elsewhere on the board
GPIOA: J4.1 (RX); also elsewhere on the board
GPIOB: J4.2 (TX); also elsewhere on the board
unnamed: C11.1, U27.3 (REF)
unnamed: L1.2, U27.4 (LX)
OD1: J1.2 (DIGITAL_OPENDRAIN); also elsewhere on the board
OD2: J2.2 (DIGITAL_OPENDRAIN); also elsewhere on the board
OD3: J3.2 (DIGITAL_OPENDRAIN); also elsewhere on the board
SCL: J4.3 (SCL), R2.1, U2.5 (A1); also elsewhere on the board
SCL_HV: U1.10 (SCL), U2.8 (B1)
SDA: J4.4 (SDA), R1.1, U2.4 (A2); also elsewhere on the board
SDA_HV: U1.9 (SDA), U2.1 (B2)
SENSE_EN: R13.2, U8.4 (EN); also elsewhere on the board
VPORT1_OUT: J1.1 (3V3); also elsewhere on the board
VPORT2_OUT: J2.1 (3V3); also elsewhere on the board
VPORT3_OUT: J3.1 (3V3); also elsewhere on the board
VREF: U1.7 (AIN3); also elsewhere on the board

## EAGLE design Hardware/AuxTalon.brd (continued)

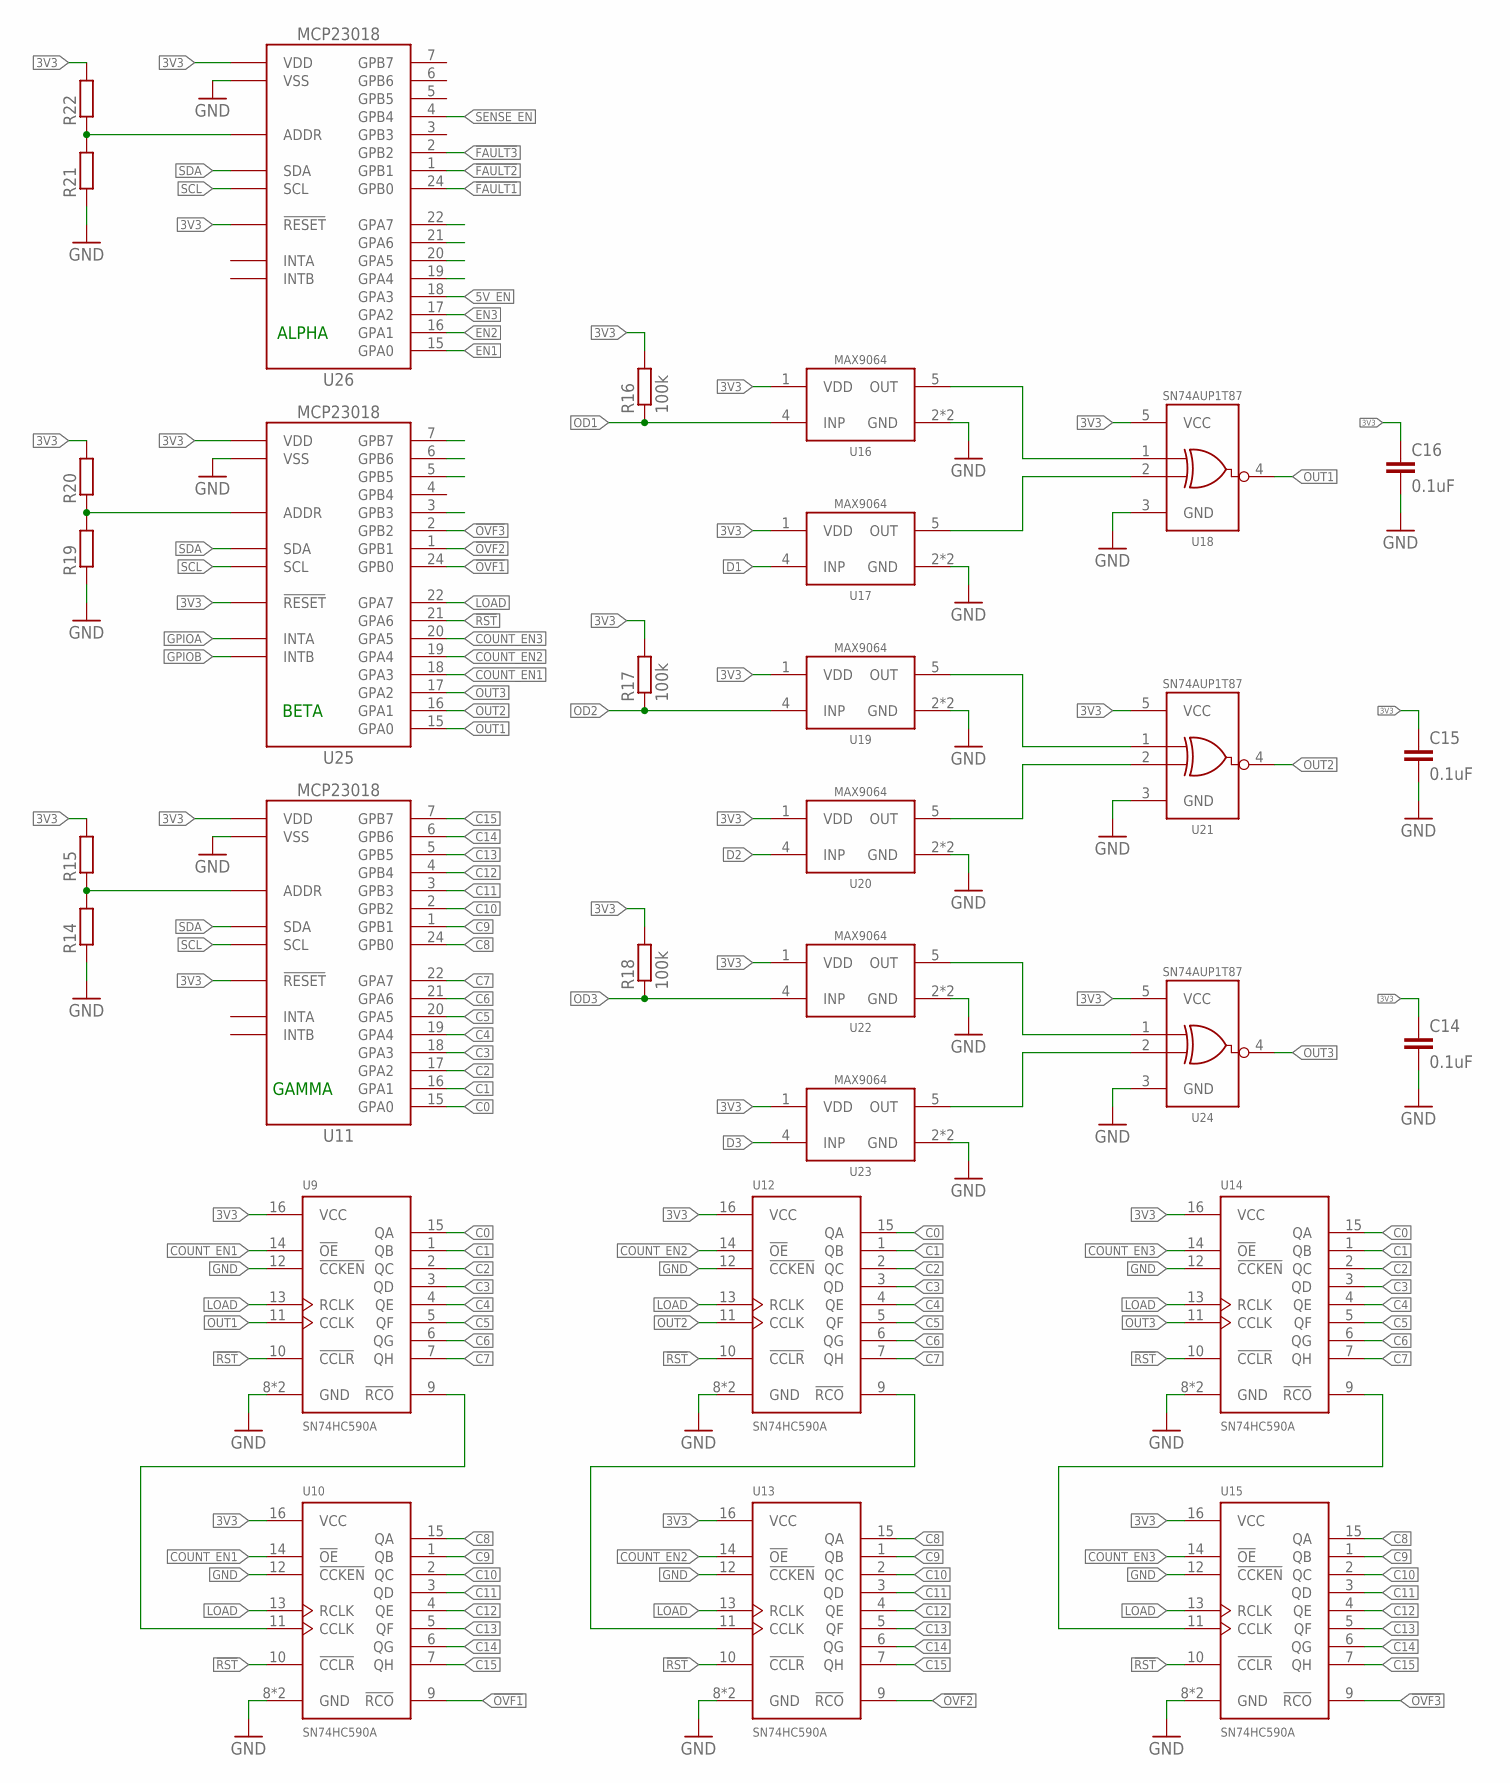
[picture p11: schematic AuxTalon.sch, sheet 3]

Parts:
C14, C15, C16: 0.1uF; C0402
R14, R15, R19, R20, R21, R22: R-EU_R0603; R0603
R16, R17, R18: 100k; R0402
U9, U10, U12, U13, U14, U15: SN74HC590AVQFN; VQFN-16
U11, U25, U26: MCP23018QFN; QFN24
U16, U17, U19, U20, U22, U23: MAX9064; SOT23-5
U18, U21, U24: SN74AUP1T87; DCK_R-PDSO-G5

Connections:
3V3: C14.1, C15.1, C16.1, R15.2, R16.2, R17.2, R18.2, R20.2, R22.2, U9.16 (VCC), U10.16 (VCC), U11.8 (VDD), U11.12 (!RESET), U12.16 (VCC), U13.16 (VCC), U14.16 (VCC), U15.16 (VCC), U16.1 (VDD), U17.1 (VDD), U18.5 (VCC), U19.1 (VDD), U20.1 (VDD), U21.5 (VCC), U22.1 (VDD), U23.1 (VDD), U24.5 (VCC), U25.8 (VDD), U25.12 (!RESET), U26.8 (VDD), U26.12 (!RESET); also elsewhere on the board
5V_EN: U26.18 (GPA3); also elsewhere on the board
!FAULT1: U26.24 (GPB0); also elsewhere on the board
!FAULT2: U26.1 (GPB1); also elsewhere on the board
!FAULT3: U26.2 (GPB2); also elsewhere on the board
!OVF1: U10.9 (!RCO), U25.24 (GPB0)
!OVF2: U13.9 (!RCO), U25.1 (GPB1)
!OVF3: U15.9 (!RCO), U25.2 (GPB2)
!RST: U9.10 (!CCLR), U10.10 (!CCLR), U12.10 (!CCLR), U13.10 (!CCLR), U14.10 (!CCLR), U15.10 (!CCLR), U25.21 (GPA6)
C0: U9.15 (QA), U11.15 (GPA0), U12.15 (QA), U14.15 (QA)
C1: U9.1 (QB), U11.16 (GPA1), U12.1 (QB), U14.1 (QB)
C2: U9.2 (QC), U11.17 (GPA2), U12.2 (QC), U14.2 (QC)
C3: U9.3 (QD), U11.18 (GPA3), U12.3 (QD), U14.3 (QD)
C4: U9.4 (QE), U11.19 (GPA4), U12.4 (QE), U14.4 (QE)
C5: U9.5 (QF), U11.20 (GPA5), U12.5 (QF), U14.5 (QF)
C6: U9.6 (QG), U11.21 (GPA6), U12.6 (QG), U14.6 (QG)
C7: U9.7 (QH), U11.22 (GPA7), U12.7 (QH), U14.7 (QH)
C8: U10.15 (QA), U11.24 (GPB0), U13.15 (QA), U15.15 (QA)
C9: U10.1 (QB), U11.1 (GPB1), U13.1 (QB), U15.1 (QB)
C10: U10.2 (QC), U11.2 (GPB2), U13.2 (QC), U15.2 (QC)
C11: U10.3 (QD), U11.3 (GPB3), U13.3 (QD), U15.3 (QD)
C12: U10.4 (QE), U11.4 (GPB4), U13.4 (QE), U15.4 (QE)
C13: U10.5 (QF), U11.5 (GPB5), U13.5 (QF), U15.5 (QF)
C14: U10.6 (QG), U11.6 (GPB6), U13.6 (QG), U15.6 (QG)
C15: U10.7 (QH), U11.7 (GPB7), U13.7 (QH), U15.7 (QH)
COUNT_EN1: U9.14 (!OE), U10.14 (!OE), U25.18 (GPA3)
COUNT_EN2: U12.14 (!OE), U13.14 (!OE), U25.19 (GPA4)
COUNT_EN3: U14.14 (!OE), U15.14 (!OE), U25.20 (GPA5)
D1: U17.4 (INP); also elsewhere on the board
D2: U20.4 (INP); also elsewhere on the board
D3: U23.4 (INP); also elsewhere on the board
EN1: U26.15 (GPA0); also elsewhere on the board
EN2: U26.16 (GPA1); also elsewhere on the board
EN3: U26.17 (GPA2); also elsewhere on the board
GND: C14.2, C15.2, C16.2, R14.1, R19.1, R21.1, U9.8 (GND), U9.12 (!CCKEN), U9.EP (GND), U10.8 (GND), U10.12 (!CCKEN), U10.EP (GND), U11.23 (VSS), U11.EP (VSS), U12.8 (GND), U12.12 (!CCKEN), U12.EP (GND), U13.8 (GND), U13.12 (!CCKEN), U13.EP (GND), U14.8 (GND), U14.12 (!CCKEN), U14.EP (GND), U15.8 (GND), U15.12 (!CCKEN), U15.EP (GND), U16.2 (GND), U16.3 (GND), U17.2 (GND), U17.3 (GND), U18.3 (GND), U19.2 (GND), U19.3 (GND), U20.2 (GND), U20.3 (GND), U21.3 (GND), U22.2 (GND), U22.3 (GND), U23.2 (GND), U23.3 (GND), U24.3 (GND), U25.23 (VSS), U25.EP (VSS), U26.23 (VSS), U26.EP (VSS); also elsewhere on the board
GPIOA: U25.14 (INTA); also elsewhere on the board
GPIOB: U25.13 (INTB); also elsewhere on the board
LOAD: U9.13 (RCLK), U10.13 (RCLK), U12.13 (RCLK), U13.13 (RCLK), U14.13 (RCLK), U15.13 (RCLK), U25.22 (GPA7)
MUX_SEL2: U25.5 (GPB5); also elsewhere on the board
unnamed: U9.9 (!RCO), U10.11 (CCLK)
unnamed: U12.9 (!RCO), U13.11 (CCLK)
unnamed: U14.9 (!RCO), U15.11 (CCLK)
unnamed: R14.2, R15.1, U11.11 (ADDR)
unnamed: U20.5 (OUT), U21.2 (B)
unnamed: U19.5 (OUT), U21.1 (A)
unnamed: U16.5 (OUT), U18.1 (A)
unnamed: U17.5 (OUT), U18.2 (B)
unnamed: U23.5 (OUT), U24.2 (B)
unnamed: U22.5 (OUT), U24.1 (A)
unnamed: R21.2, R22.1, U26.11 (ADDR)
unnamed: R19.2, R20.1, U25.11 (ADDR)
OD1: R16.1, U16.4 (INP); also elsewhere on the board
OD2: R17.1, U19.4 (INP); also elsewhere on the board
OD3: R18.1, U22.4 (INP); also elsewhere on the board
OUT1: U9.11 (CCLK), U18.4 (Y), U25.15 (GPA0)
OUT2: U12.11 (CCLK), U21.4 (Y), U25.16 (GPA1)
OUT3: U14.11 (CCLK), U24.4 (Y), U25.17 (GPA2)
SCL: U11.9 (SCL), U25.9 (SCL), U26.9 (SCL); also elsewhere on the board
SDA: U11.10 (SDA), U25.10 (SDA), U26.10 (SDA); also elsewhere on the board
SENSE_EN: U26.4 (GPB4); also elsewhere on the board

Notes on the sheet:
BETA
GAMMA
ALPHA

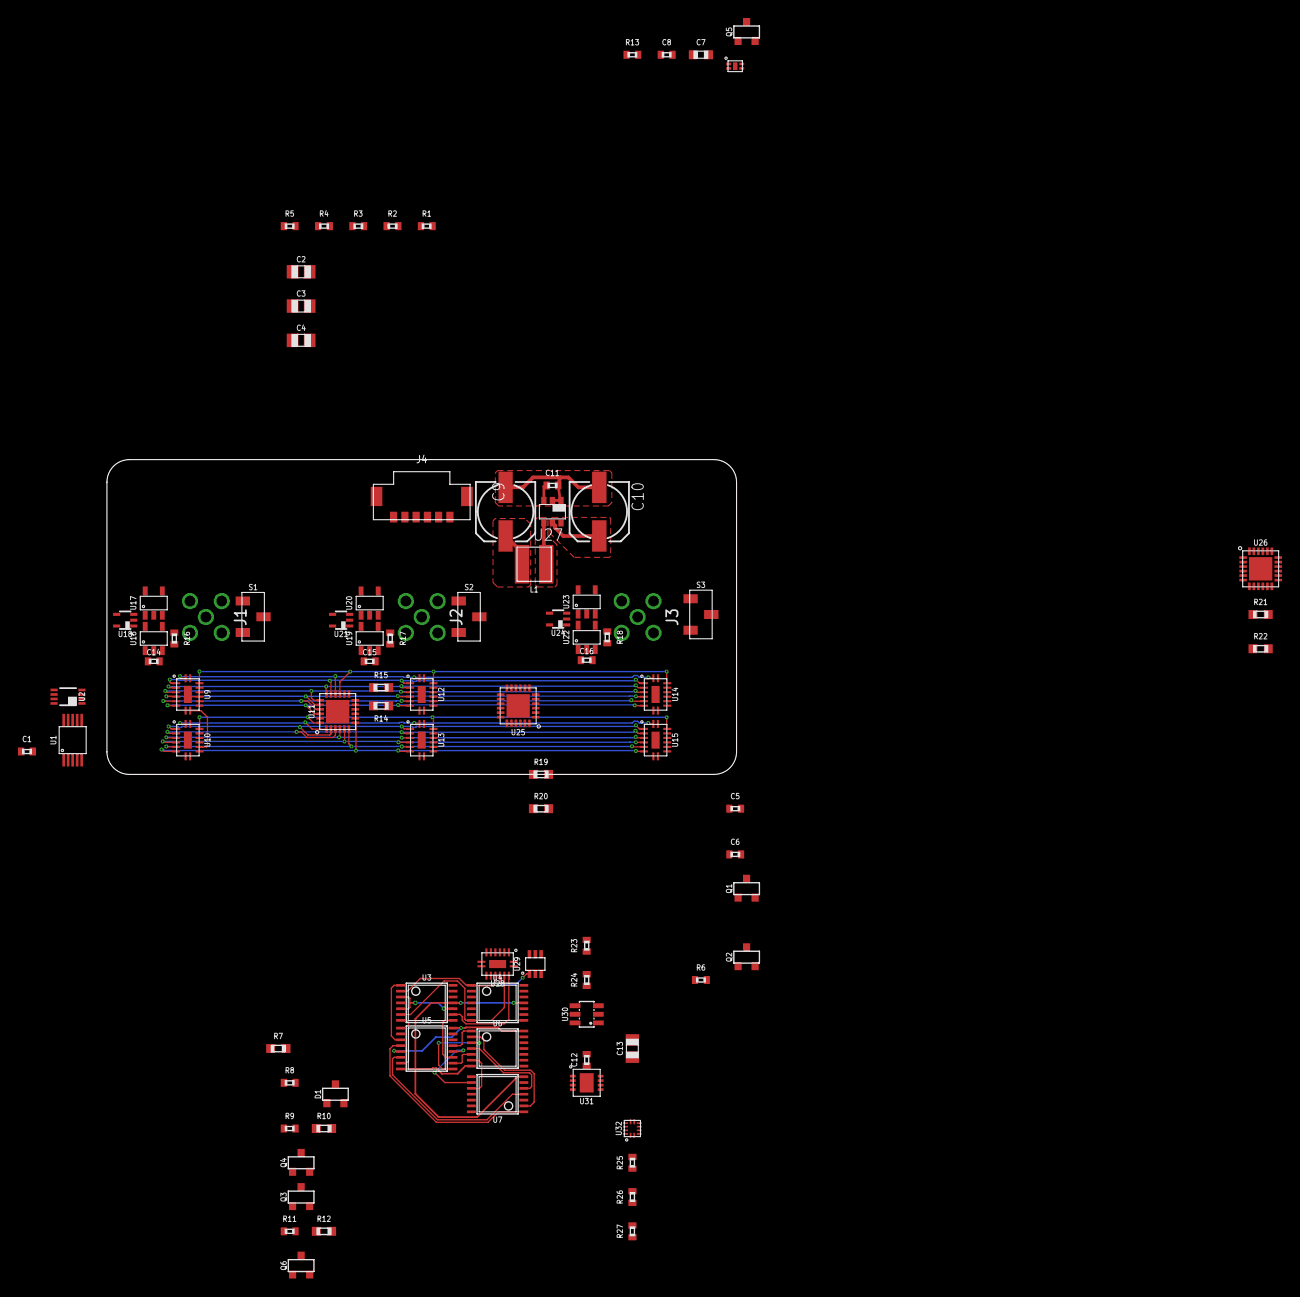
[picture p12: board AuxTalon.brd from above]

Board: 2 copper layers, 70.0 x 35.0 mm, 90 parts (0 on the bottom side), 107 nets.

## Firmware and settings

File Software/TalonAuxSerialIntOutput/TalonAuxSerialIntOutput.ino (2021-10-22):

#include <Wire.h>
#include <Arduino.h>
#include <MCP23018.h>

// #define OVERFLOW_ONLY 

//Input Pins
const uint8_t GPIOA = 5;
const uint8_t GPIOB = 6;

//IO Expander Pins - ALPHA
const uint8_t REG_EN = 7;
const uint8_t ADC_INT = 6;

//IO Expander Pins - BETA
const uint8_t LOAD = 7;
const uint8_t RST = 6;
const uint8_t OUT1 = 0;
// const uint8_t COUNT_EN3 = 5;
// const uint8_t COUNT_EN2 = 4;
const uint8_t COUNT_EN1 = 3;
const uint8_t OVF1 = 8;

//Configured for pins on the Particle Boron
//const uint8_t EXT_EN = 8;
//const uint8_t SDA_CTRL = 2;

const uint8_t EXT_EN = 13;
const uint8_t SDA_CTRL = 5;

volatile bool OverflowFlags[3] = {0}; //Set by OverflowISR, cleared in main loop
volatile bool EventFlags[3] = {0}; //Set by EventISR, cleared in main loop

volatile bool NewOverflow = false; //Used to indicate a new overflow condition
volatile bool NewEvent = false; //Used to indicate a new event condition

char ReadArray[25] = {0};

MCP23018 ioAlpha(0x23); //FIX! RETURN to 0x20
MCP23018 ioBeta(0x20); //FIX! RETURN to 0x23
MCP23018 ioGamma(0x24);


void setup() {

	// pinMode(EXT_EN, OUTPUT); 
	// digitalWrite(EXT_EN, HIGH);
	Serial.begin(115200);
	// delay(5000);
	// pinMode(SDA_CTRL, OUTPUT);
	// digitalWrite(SDA_CTRL, LOW);
	// delay(5000);
	ioAlpha.begin();
	ioBeta.begin();
	ioGamma.begin();
	// Wire.begin();
 //DEBUG1!
	SetDefaultPins(); //Set the default configuration for sensing 
	attachInterrupt(digitalPinToInterrupt(GPIOA), EventISR, FALLING); //Setup interrupt for GPIOA
	attachInterrupt(digitalPinToInterrupt(GPIOB), OverflowISR, FALLING); //Setup interrupt for GPIOA
	delay(1000);

	Serial.println("Begin Aux Demo...");
}

void loop() {
	while(1) {
		if(NewOverflow) {
			Serial.print("OVERFLOW:\t");
			for(int i = 0; i < 3; i++) { //Find more elegant solution??
				Serial.print(OverflowFlags[i]);
				Serial.print("\t");
				OverflowFlags[i] = 0; //clear flag once printed out
			}
			Serial.print("\n");
			NewOverflow = false; //Clear indicator flag once done printing
		}

		#if !defined(OVERFLOW_ONLY) //Don't print out all the pulses if we only want to look at overflow events
			if(NewEvent) {
				Serial.print("EVENT:\t");
				for(int i = 0; i < 3; i++) { //Find more elegant solution??
					Serial.print(EventFlags[i]);
					Serial.print("\t");
					EventFlags[i] = 0; //clear flag once printed out
				}
				Serial.print("\n");
				NewEvent = false; //Clear indicator flag once done printing
			}
		#endif
	}
}

void SetDefaultPins()
{
	for(int i = 0; i < 16; i++) { //Set all Gamma pins to input
		ioGamma.pinMode(i, INPUT);
	} 

	for(int i = 0; i < 3; i++) { //Set each group of IO pins seperately
		ioBeta.pinMode(OUT1 + i, INPUT); //Set all outputs from counters as inputs to I/O expander
		ioBeta.pinMode(COUNT_EN1 + i, OUTPUT); //Set enable control as output
		ioBeta.pinMode(OVF1 + i, INPUT); //Set overflow pins as inputs
		ioBeta.digitalWrite(COUNT_EN1 + 1, HIGH); //Default to enable all counters
		ioBeta.setIntPinConfig(OVF1 + i, false, 1); //Set overflow pins to trigger an interrupt whenever they are low
		ioBeta.setIntPinConfig(OUT1 + i, true); //Set output pins to trigger an interrupt anytime they change from the previous value
		ioBeta.setInterrupt(OVF1 + i, true); //Turn on interrupt for overflow pins
		ioBeta.setInterrupt(OUT1 + i, true); //Turn on interrupt for output pins
	}
	ioBeta.pinMode(LOAD, OUTPUT);
	ioBeta.pinMode(RST, OUTPUT);
	ioBeta.digitalWrite(LOAD, LOW); //Start with load in low position, will load on high going edge
	ioBeta.digitalWrite(RST, HIGH); //Negate reset by default

	ioAlpha.pinMode(REG_EN, OUTPUT);
	ioAlpha.digitalWrite(REG_EN, HIGH); //Default 5V to on
	ioAlpha.pinMode(ADC_INT, INPUT_PULLUP); //Setup ADC int as an input pullup for the open drain
	ioBeta.clearInterrupt(BOTH); //Make sure there are no pending interrupts 
}


uint16_t ReadCounters(uint8_t Port, bool NewRead) //Pass in which counter to read
{
	// static uint16_t Count1 = 0; //Keep all counters as local statics to be returned at request
	// static uint16_t Count2 = 0;
	// static uint16_t Count3 = 0; 

	static uint16_t Count[3] = {0}; //Keep all counters as local statics to be returned at request 

	if(NewRead) {
		ioBeta.digitalWrite(LOAD, HIGH); //Load all values
		delayMicroseconds(1); //Delay min number of microseconds to ensure a pulse
		ioBeta.digitalWrite(LOAD, LOW);

		for(int i = 0; i < 3; i++) { //Get count n
			ioBeta.digitalWrite(COUNT_EN1 + i, HIGH); //Turn on outputs of counter n 
			Count[i] = ioGamma.readBus(); //Grab bus
			ioBeta.digitalWrite(COUNT_EN1 + i, LOW); //Turn off outputs of countern
		}

		// ioBeta.digitalWrite(COUNT_EN1, HIGH); //Get count 1
		// Count1 = ioGamma.readWord();
		// ioBeta.digitalWrite(COUNT_EN1, LOW);

		// ioBeta.digitalWrite(COUNT_EN2, HIGH); //Get count 2
		// Count2 = ioGamma.readWord();
		// ioBeta.digitalWrite(COUNT_EN2, LOW);

		// ioBeta.digitalWrite(COUNT_EN3, HIGH); //Get count 3
		// Count3 = ioGamma.readWord();
		// ioBeta.digitalWrite(COUNT_EN3, LOW);
	}

	return Count[Port]; //Return the desired 16 bit count
}

void ClearCounters() //Clear all counters
{
	ioBeta.digitalWrite(RST, LOW);
	// ASM('NOP'); //Delay minimal time, needs only to be longer than 200ns, can likely eliminate delay
	delayMicroseconds(1); //Delay min number of microseconds to ensure a pulse
	ioBeta.digitalWrite(RST, HIGH);
}

void EventISR()
{
	NewEvent = true; //Set indicator flag
	for(int i = 0; i < 3; i++) {
		EventFlags[i] = ioBeta.getInterrupt(OUT1 + i); //Grab each interrupt flag
	}
	// EventFlags[0] = ioBeta.getInterrupt(OUT1); //DEBUG!
	ioBeta.clearInterrupt(A); //Clear interrupt A
}

void OverflowISR()
{
	NewOverflow = true; //Set indicator flag
	for(int i = 0; i < 3; i++) {
		OverflowFlags[i] = ioBeta.getInterrupt(OVF1 + i); //Grab each interrupt flag
	}
	ioBeta.clearInterrupt(B); //Clear interrupt B
}

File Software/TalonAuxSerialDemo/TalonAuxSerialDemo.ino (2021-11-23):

#include <Wire.h>
 // #include "Adafruit_MCP23008.h"
// #include <Adafruit_MCP23X17.h>
// #include <MCP2301x.h>
#include <Arduino.h>
#include <MCP23018.h>

// #define NUM_MCP2301x_ICs   1

//Input Pins
const uint8_t TX = 1;
const uint8_t RX = 0;

//IO Expander Pins - ALPHA
const uint8_t REG_EN = 7;
const uint8_t ADC_INT = 6;

//IO Expander Pins - BETA
const uint8_t LOAD = 7;
const uint8_t RST = 6;
const uint8_t OUT1 = 0;
// const uint8_t COUNT_EN3 = 5;
// const uint8_t COUNT_EN2 = 4;
const uint8_t COUNT_EN1 = 3;
const uint8_t OVF1 = 8;

const uint8_t EN1 = 1;
const uint8_t FAULT1 = 0;

//Configured for pins on the Particle Boron
//const uint8_t EXT_EN = 8;
//const uint8_t SDA_CTRL = 2;

 const uint8_t EXT_EN = 13;
 const uint8_t SDA_CTRL = 5;

char ReadArray[25] = {0};

 // Adafruit_MCP23008 io;
// Adafruit_MCP23X17 io;
MCP23018 ioAlpha(0x20);
MCP23018 ioBeta(0x23);
MCP23018 ioGamma(0x24);
// MCP2301x io;

// #define IOEXP_MODE  (IOCON_INTCC | IOCON_INTPOL | IOCON_ODR | IOCON_MIRROR)
// #define ADDRESS      (MCP2301X_CTRL_ID+7)
// #define LED_PIN      D4   // WeMOS D1 & D1 mini
// #define IN_PORT      0
// #define OUT_PORT     1

// #define RELAY_ON      LOW
// #define RELAY_OFF     HIGH
// #define ALL_OFF       ALL_LOW

// #define DIR 0x00
// #define GPIO 0x12
// #define LAT 0x14
// #define PU 0x0C
// #define ADR 0x20

///////////// ANALOG SENSING /////////////
#include <Adafruit_ADS1015.h>

Adafruit_ADS1115 ads(0x49); 

const float VoltageDiv = 0.1875; //Program voltage divider [mV/bit]

void setup() {

	pinMode(EXT_EN, OUTPUT); 
	digitalWrite(EXT_EN, HIGH);
	Serial.begin(115200);
	// delay(5000);
	pinMode(SDA_CTRL, OUTPUT);
	digitalWrite(SDA_CTRL, LOW);
	delay(5000);

	Wire.begin();
	Serial.println(ioAlpha.begin());
	Serial.println(ioBeta.begin());
	Serial.println(ioGamma.begin());
 //DEBUG1!
	SetDefaultPins(); //Set the default configuration for sensing 
	delay(1000);
	Serial.println("Begin Aux Demo...");
}

void loop() {
	// io.pinMode(0, TX, LOW);
	// io.pinMode(0, FOut, LOW);
	// delay(1000);
	// io.pinMode(0, FOut, LOW);
	// io.pinMode(0, TX, HIGH);
	// delay(1000);
	// io.pinMode(0, FOut, HIGH);
	// io.pinMode(0, TX, LOW);
	// delay(1000);
	// io.pinMode(0, FOut, HIGH);
	// io.pinMode(0, TX, HIGH);
	// delay(1000);
	static int ReadLength = 0;
  	String ReadString;
	if(Serial.available() > 0) {
    char Input = Serial.read();

    // Increment counter while waiting for carrage return or newline
    // if(Input != 13 || Input != 10) {
    if(Input != '#') { //Wait for SDI12 line end or control line end 
//      Serial.println(Input); //DEBUG!
      ReadArray[ReadLength] = Input;
//      Serial.println(ReadArray[ReadLength]); //DEBUG!
      ReadLength++;
    }

    // if(Input == 13 || Input == 10) { // carriage or newline
	//Format - ppCs#
	//pp - two digit pin number (base 10)
	//C - command ('M' - Mode, 'R' - Read, 'W' - Write)
	//s - state (0 - Output/Off, 1 - Input/On), required only for write and mode operations 
	if(Input == '#') { //Control line ending
		ReadString = String(ReadArray);
		ReadString.trim();
		memset(ReadArray, 0, sizeof(ReadArray));
		ReadLength = 0;
		int Val = (ReadString.substring(0,2)).toInt(); //Grab the pin to operate on
		String Operation = ReadString.substring(2,3); //Grab the middle char
		int State = (ReadString.substring(3,4)).toInt(); //Grab the state to set
		unsigned int Result = 0; //Used to grab result of either setting of pin mode or response from a read

		if(Operation.equals("M")) { //if call is for pinmode setting
			Result = ioAlpha.pinMode(Val, !State); //Use inverse of state to corespond with 1 = input, 0 = output
		}

		if(Operation.equals("m")) { //if call is for taking measurment of counter
			Result = ReadCounters(Val, true); //Return desired counter after taking new measure
		}
		
		if(Operation.equals("R")) { //If call is for digital read
			Result = ioAlpha.digitalRead(Val);
		}

		if(Operation.equals("r")) { //if call is for taking reading of counter
			Result = ReadCounters(Val, false); //Read previously retrived value for counter
		}

		if(Operation.equals("W")) { //If call is for digital write
			Result = ioAlpha.digitalWrite(Val, State);

		}

		if(!Operation.equals("S")) { //If any function but voltage sense called, report normally
			Serial.print(">");
			Serial.println(ReadString); //Echo back to serial monitor
			Serial.print(">");
			Serial.println(Result); //Return various result 
		}

		if(Operation.equals("S")) { //Run voltage sense program
			VoltageSense();
		}
		
	}
	// GetAddress();
	// delay(5000);

}
}

void SetDefaultPins()
{
	for(int i = 0; i < 16; i++) { //Set all Gamma pins to input
		ioGamma.pinMode(i, INPUT_PULLUP);
	} 

	for(int i = 8; i < 16; i++) { //Set all Alpha pins to input
		ioAlpha.pinMode(i, INPUT_PULLUP);
		// ioAlpha.pinMode(i, OUTPUT);
		// ioAlpha.digitalWrite(i, LOW);
	} 

	for(int i = 11; i < 16; i++) { //Set all Beta pins to input
		ioBeta.pinMode(i, INPUT_PULLUP);
		// ioBeta.pinMode(i, OUTPUT);
		// ioBeta.digitalWrite(i, LOW);
	} 


	for(int i = 0; i < 3; i++) { //Set each group of IO pins seperately
		ioBeta.pinMode(OUT1 + i, INPUT); //Set all outputs from counters as inputs to I/O expander
		ioBeta.pinMode(COUNT_EN1 + i, OUTPUT); //Set enable control as output
		ioBeta.pinMode(OVF1 + i, INPUT); //Set overflow pins as inputs
		ioBeta.digitalWrite(COUNT_EN1 + i, HIGH); //Default to enable all counters
		ioAlpha.pinMode(FAULT1 + 2*i, INPUT_PULLUP);
		ioAlpha.pinMode(EN1 + 2*i, OUTPUT);
		ioAlpha.digitalWrite(EN1 + 2*i, HIGH);
	}
	ioBeta.pinMode(LOAD, OUTPUT);
	ioBeta.pinMode(RST, OUTPUT);
	ioBeta.digitalWrite(LOAD, LOW); //Start with load in low position, will load on high going edge
	ioBeta.digitalWrite(RST, HIGH); //Negate reset by default

	ioAlpha.pinMode(REG_EN, OUTPUT);
	ioAlpha.digitalWrite(REG_EN, HIGH); //Default 5V to on
	// ioAlpha.pinMode(ADC_INT, INPUT_PULLUP); //Setup ADC int as an input pullup for the open drain
	ioAlpha.pinMode(ADC_INT, INPUT); //Setup ADC int as an input pullup for the open drain
}

void VoltageSense() //Voltage sense (AKA Sensor0)
{
	Serial.print(">Voltage Sense:\n");
	ads.begin();

	for(int i = 0; i < 4; i++){ //Increment through 4 voltages
  		Serial.print("\tPort");
  		Serial.print(i);
  		Serial.print(": ");
  		Serial.print(ads.readADC_SingleEnded(i)*VoltageDiv, 4); //Print high resolution voltage
  		Serial.print(" mV\n");  
	}
}
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

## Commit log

2021-09-23 Prelim Schematic Capture
    About 90% done with schematic capture
    [AuxTalon.brd, AuxTalon.sch]
2021-10-07 Preliminary work done on AuxTalon
    [AuxTalon.brd, AuxTalon.sch]
2021-10-07 Preliminary copper layout done on Load Switch Aux Talon
    Switched to Aux Talon using self contained load switches in order to reduce layout size. Preliminary copper layout done, addition of ESD diodes and review still required.
    [AuxTalon_LoadSwitch.brd, AuxTalon_LoadSwitch.sch]
2021-10-07 Added ESD diodes, moved connector positioning
    Added some ESD diodes on signal lines and changed positioning of connectors to restrict install to a single direction
    [AuxTalon_LoadSwitch.brd, AuxTalon_LoadSwitch.sch]
2021-10-12 Layout, gerbers, and BoM for v0.0 - sent to fab
    [AuxTalon_LoadSwitch.brd, AuxTalon_LoadSwitch.sch, AuxTalon_LoadSwitch_0v0_BoM.csv]
2021-10-14 v0.1 Updates - Added EEPROM
    Added EEPROM to board
    [AuxTalon_LoadSwitch.brd, AuxTalon_LoadSwitch.sch]
2021-10-14 Generated documentation for v0.1 quote
    [AuxTalon_LoadSwitch_0v1_BoM.csv]
2021-10-22 Added serial firmware demos
    Added demo for reading of counters and general serial control, also added demo for testing interrupt interfacing
2021-11-23 v1.0 Updates
    Added voltage sensing for ports, swapped 5V converter, sent v1.0 to fab
    [AuxTalon_LoadSwitch.brd, AuxTalon_LoadSwitch.sch]
2021-12-08 Update part val, generated BoM for v1.0
    [AuxTalon_LoadSwitch.brd, AuxTalon_LoadSwitch.sch, AuxTalon_LoadSwitch_1v0_BoM.csv]
2021-12-08 Updated solder paste
    [AuxTalon_LoadSwitch.brd, AuxTalon_LoadSwitch.sch]
2021-12-10 v1.1 update
    Moved via
    [AuxTalon_LoadSwitch.brd]
2022-02-11 Prelim v1.3 updates
    [AuxTalon_LoadSwitch.brd, AuxTalon_LoadSwitch.sch]
2022-02-13 v1.3 Layout
    [AuxTalon_LoadSwitch.brd]
2022-04-06 Updated part vals for v1.3
    [AuxTalon_LoadSwitch.brd, AuxTalon_LoadSwitch.sch, AuxTalon_LoadSwitch_1v3_BoM.csv]
2022-04-06 Updates for modified BoM
    [AuxTalon_LoadSwitch.brd, AuxTalon_LoadSwitch.sch, AuxTalon_LoadSwitch_1v3_BoM_2022-04-06.csv]
2022-04-25 v1.4 Updates
    Updated schematic and layout, boards sent to fab
    [AuxTalon_LoadSwitch.brd, AuxTalon_LoadSwitch.sch]
2023-05-15 Production files for v1.4
    [AuxTalon_LoadSwitch_1v4_BoM_2022-05-03.csv, AuxTalon_LoadSwitch_1v4_BoM_2023-01-06.csv]
2023-05-15 Updates for v1.5
    - Changed load switch
    [AuxTalon_LoadSwitch.brd, AuxTalon_LoadSwitch.sch, AuxTalon_LoadSwitch_1v5_BoM_2023-05-10.csv]
2023-07-07 Changed Cout value
    Changed `C13`, `C18`, `C20` from 1uF to 10uF
    [AuxTalon_LoadSwitch.brd, AuxTalon_LoadSwitch.sch]
2024-09-01 Updated README and board images
